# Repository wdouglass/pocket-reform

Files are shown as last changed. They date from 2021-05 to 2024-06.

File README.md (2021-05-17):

# MNT Pocket Reform (Research Project)

## License

Copyright 2021 MNT Research GmbH.

The following licenses are used in the project, unless specified differently in a particular subfolder:

- Schematics, PCBs: [CERN-OHL-S v2](https://www.ohwr.org/project/cernohl/wikis/uploads/002d0b7d5066e6b3829168730237bddb/cern_ohl_s_v2.txt)
- Other documentation, artwork, photos and drawings that are not trademarks (see below): [CC-BY-SA 4.0](https://creativecommons.org/licenses/by-sa/4.0/legalcode)
- Software, firmware: Various. [GPL 3.0](https://www.gnu.org/licenses/gpl-3.0.en.html) if not specified otherwise in the file/subdirectory.

The "MNT" and "MNT REFORM" logos are trademarks of MNT Research GmbH. You may not use these in derived works. The reason for this is that we cannot be responsible for regulatory issues with derived boards and we cannot support them. If someone sees an MNT brand on a product, it has to be clear that it comes from MNT Research and not from a third party.

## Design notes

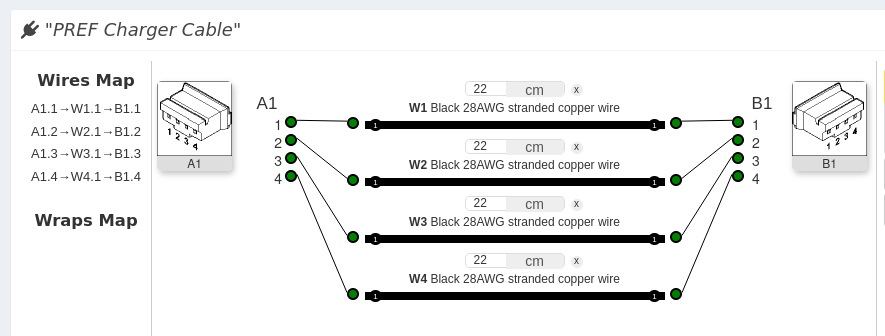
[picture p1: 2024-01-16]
pocket-reform-cables/pref-charger-cable.png

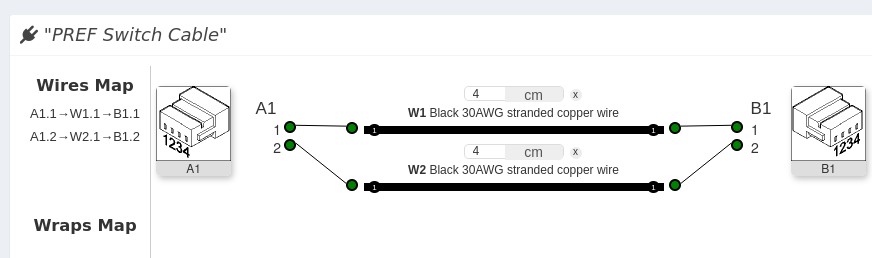
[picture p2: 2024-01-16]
pocket-reform-cables/pref-switch-cable.png

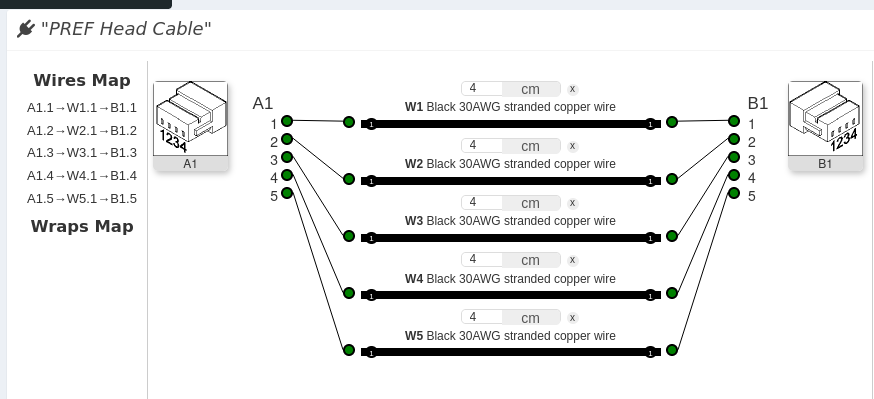
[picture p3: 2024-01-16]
pocket-reform-cables/pref-head-cable.png

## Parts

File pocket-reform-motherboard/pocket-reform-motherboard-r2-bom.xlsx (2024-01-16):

Reference | Value | Footprint | Manufacturer | Manufacturer_No | Qty
C1, C3, C13, C20, C25, C27-C33, C35, C38, C40, C42-C50, C53-C55, C57, C59-C64, C66, C68-C81, C84-C93, C95, C97, C99, C101, C104, C108, C109 | 0.1uF | Capacitor_SMD:C_0402_1005Metric | Samsung | CL05B104KO5NNNC | 66
C2, C4, C5, C39, C51, C56, C65, C98, C105, C107 | 10uF | Capacitor_SMD:C_0603_1608Metric | Samsung | CL10A106MO8NQNC | 10
C6, C17 | 22uF | Capacitor_SMD:C_0603_1608Metric | Samsung | CL10A226MP8NUNE | 2
C7, C8, C11, C12, C18, C19, C52, C58 | 10nF | Capacitor_SMD:C_0603_1608Metric | Samsung | CL10B103KB8NNNC | 8
C9, C10, C26, C34, C36, C41 | 1uF | Capacitor_SMD:C_0603_1608Metric | Samsung | CL10A105KB8NNNC | 6
C14, C83, C123, C124, C126 | 47uF | Capacitor_SMD:C_0603_1608Metric | Murata | GRM188R60J476ME15D | 5
C15, C16 | 330uF | Capacitor_SMD:CP_Elec_6.3x5.4 | Lelon | VZT331M0JTR-0606ACS | 2
C21, C23 | 18pF | Capacitor_SMD:C_0603_1608Metric | Yageo | CC0603JRNPO9BN180 | 2
C22, C24 | 27pF | Capacitor_SMD:C_0603_1608Metric | Yageo | CC0603JRNPO9BN270 | 2
C37 | 1nF | Capacitor_SMD:C_0603_1608Metric | Yageo | CC0603KRX7R9BB102 | 1
C67, C106 | 22uF | Capacitor_SMD:C_0805_2012Metric | Samsung | CL10A226MP8NUNE | 2
C82 | 470nF | Capacitor_SMD:C_0603_1608Metric | Samsung | CL10B474KA8NNNC | 1
C94, C100 | 10uF | Capacitor_SMD:C_0402_1005Metric | Samsung | CL05A106MP5NUNC | 2
C96 | DNP | Capacitor_SMD:C_0402_1005Metric | Samsung | CL05B104KO5NNNC | 1
C102, C103 | 47uF | Capacitor_SMD:C_1206_3216Metric | Murata | GRM31CR61A476ME15L | 2
D1 | LED_MODEM | LED_SMD:LED_0603_1608Metric | Everlight | 19-217/R6C-AL1M2VY/3T | 1
D2, D4-D6 | PMEG4050EP,115 | Diode_SMD:D_SOD-128 | Nexperia | PMEG4050EP,115 | 4
D3 | PMEG1020EA,115 | Diode_SMD:D_SOD-323 | Nexperia | PMEG1020EA,115 | 1
D8, D9 | LED_Small | LED_SMD:LED_0603_1608Metric | Everlight | 19-217/R6C-AL1M2VY/3T | 2
D10 | 19-337/R6GHBHC-A01/2T | footprints:LED_19-337_R6GHBHC-A01_2T | Everlight | 19-337/R6GHBHC-A01/2T | 1
D11 | SS54 | Diode_SMD:D_SMA | MDD | SS54 | 1
D12 | SD0603S040S0R2 | Diode_SMD:D_0603_1608Metric | AVX | SD0603S040S0R2 | 1
D23 | LED_NVME | LED_SMD:LED_0603_1608Metric | Everlight | 19-217/R6C-AL1M2VY/3T | 1
FB1, FB7, FB11 | 220@100MHz 1.4A | Inductor_SMD:L_0603_1608Metric | Murata | BLM18KG221SN1D | 3
FB2-FB4, FB6, FB8-FB10, FB12-FB16 | 100@100MHz 3A | Inductor_SMD:L_0603_1608Metric | Murata | BLM18PG121SN1D | 12
FB5 | DNP | Inductor_SMD:L_0603_1608Metric | Murata | BLM18PG121SN1D | 1
H5, H7 | NGFF-Mount1 | footprints:WA-SMSI-M2 | Wurth | SMTSO2020CTJ | 2
H8, H9 | MountingHole_Pad | footprints:WA-SMSI-M2 | Sinhoo | SMTSO2020CTJ | 2
J1 | CHARGER | Connector_JST:JST_PH_S9B-PH-SM4-TB_1x09-1MP_P2.00mm_Horizontal | HR(Joint Tech Elec) | A2001WR-S-09PD01 | 1
J2 | DM3AT-SF-PEJM5 | footprints:DM3AT-SF-PEJM5 | Hirose | DM3AT-SF-PEJM5 | 1
J3, J14 | USB_C_Receptacle | footprints:MOLEX_105450-0101 | Molex | 105450-0101 | 2
J4 | 9452812561 | footprints:09452812561 | HARTING | 9452812561 | 1
J5 | SYSCTL | Connector_JST:JST_SH_SM04B-SRSS-TB_1x04-1MP_P1.00mm_Horizontal | JST | SM04B-SRSS-TB(LF)(SN) | 1
J6 | USB_INT1 | Connector_JST:JST_SH_SM04B-SRSS-TB_1x04-1MP_P1.00mm_Horizontal | JST | SM04B-SRSS-TB(LF)(SN) | 1
J7 | HDMI_D_1.4 | Connector_HDMI:HDMI_Micro-D_Molex_46765-0x01 | Molex | 467650001 | 1
J8 | SIM_Card | footprints:MOLEX_78800-0001 | Molex | 788000001 | 1
J9 | USB_C_Receptacle_USB2.0 | Connector_USB:USB_C_Receptacle_HRO_TYPE-C-31-M-12 | Korean Hroparts | TYPE-C-31-M-12 | 1
J10 | 1-2199230-6 | footprints:TE_1-2199230-6 | TE | 1-2199230-6 | 1
J11 | Conn_01x33 | Connector_FFC-FPC:Hirose_FH12-33S-0.5SH_1x33-1MP_P0.50mm_Horizontal | Jushuo | AFC07-S33FCC-00 | 1
J12 | 2199230-5 | footprints:TE_2199230-5 | TE | 1-2199230-5 | 1
J13 | FH35C-31S-0.3HW(50) | footprints:TE_3-2328724-1 | TE | 3-2328724-1 | 1
J15 | CONN_SPK | Connector_Molex:Molex_PicoBlade_53261-0271_1x02-1MP_P1.25mm_Horizontal | Molex | 53261-7002 | 1
J16 | SAMTEC_TSM-106-02-X-SH-A | footprints:SAMTEC_TSM-106-02-X-SH-A | Samtec | TSM-106-01-T-SH | 1
J17 | POWSW | Connector_JST:JST_SH_SM02B-SRSS-TB_1x02-1MP_P1.00mm_Horizontal | JST | SM02B-SRSS-TB(LF)(SN) | 1
J18 | CONN_HEAD | Connector_JST:JST_SH_SM05B-SRSS-TB_1x05-1MP_P1.00mm_Horizontal | JST | SM05B-SRSS-TB(LF)(SN) | 1
J20 | QWIIC | Connector_JST:JST_SH_SM04B-SRSS-TB_1x04-1MP_P1.00mm_Horizontal | JST | SM04B-SRSS-TB(LF)(SN) | 1
J21 | USBSEL | Connector_PinHeader_2.00mm:PinHeader_2x03_P2.00mm_Vertical_SMD | Harwin | M22-5320305 | 1
L1 | 22uH | Inductor_SMD:L_Taiyo-Yuden_NR-30xx | YJYCOIN | YNR3015-150M | 1
L2 | 3.3uH | Inductor_SMD:L_1210_3225Metric | Murata | LQH32PN3R3NN0L | 1
L3, L4 | 15uH | Inductor_SMD:L_Vishay_IHLP-4040 | Vishay | IHLP4040DZER150M11 | 2
L5, L6 | 15uH | Inductor_SMD:L_Taiyo-Yuden_NR-30xx | Taiyo Yuden | NRH3012T150MN | 2
R1, R29, R34-R36, R58, R60, R61, R110 | 1k | Resistor_SMD:R_0402_1005Metric | Yageo | RC0402FR-071KL | 9
R2 | 1M | Resistor_SMD:R_0402_1005Metric | Yageo | AC0402FR-071ML | 1
R3 | 90.9K 1% | Resistor_SMD:R_0402_1005Metric | UNI-ROYAL | 0402WGF9092TCE | 1
R4, R5, R9, R11-R13, R19, R27, R33, R44-R46, R50, R53, R54, R65-R67, R81, R103-R109, R111 | 0 | Resistor_SMD:R_0402_1005Metric | Panasonic | ERJ2GE0R00X | 27
R6-R8, R69, R70, R87 | 100k | Resistor_SMD:R_0402_1005Metric | Yageo | RC0402FR-07100KL | 6
R10, R15, R17, R20, R22, R24, R26, R28, R30, R38, R52, R56, R68, R72, R75, R85, R96 | 10k | Resistor_SMD:R_0402_1005Metric | Yageo | RC0402FR-0710KL | 17
R14 | 8.25k | Resistor_SMD:R_0402_1005Metric | UNI-ROYAL | 0402WGF8251TCE | 1
R16 | 3.16k | Resistor_SMD:R_0402_1005Metric | Yageo | RC0402FR-073K16L | 1
R18 | 5.76k | Resistor_SMD:R_0402_1005Metric | UNI-ROYAL | 0402WGF5761TCE | 1
R21, R55, R62, R74, R78, R86, R88 | DNP | Resistor_SMD:R_0402_1005Metric | DNP | DNP | 7
R23 | 9.53K 1% | Resistor_SMD:R_0402_1005Metric | FH | RC-02W9531FT | 1
R25, R42, R43, R57, R59, R89, R93, R95, R101 | 4.7k | Resistor_SMD:R_0402_1005Metric | Yageo | RC0402FR-074K7L | 9
R37, R39-R41 | 75 1% | Resistor_SMD:R_0402_1005Metric | Panasonic | ERJ2RKF75R0X | 4
R47, R48 | 27.4 | Resistor_SMD:R_0402_1005Metric | UNI-ROYAL | 0402WGF274JTCE | 2
R64 | 2.2k | Resistor_SMD:R_0402_1005Metric | Yageo | RC0402FR-072K2L | 1
R73, R97-R100 | 47k | Resistor_SMD:R_0402_1005Metric | Yageo | AC0402FR-0747KL | 5
R76, R77, R79, R80, R82 | 33 | Resistor_SMD:R_0402_1005Metric | Yageo | RC0402FR-0733RL | 5
R83, R84 | 22k | Resistor_SMD:R_0402_1005Metric | Yageo | AC0402FR-0722KL | 2
R90 | 27k | Resistor_SMD:R_0402_1005Metric | Panasonic | ERJ2RKF2702X | 1
R198, R199 | 49.9 | Resistor_SMD:R_0402_1005Metric | Yageo | RC0402FR-0749R9L | 2
SW1 | SW_DIP_x01 | Button_Switch_SMD:SW_DIP_SPSTx01_Slide_Omron_A6S-110x_W8.9mm_P2.54mm | Dongguan Guangzhu | DSIC01LSGET | 1
SW2 | RESET | Button_Switch_SMD:SW_Push_1P1T_NO_CK_KMR2 | XKB | TS-1185EC-C-D-B | 1
TP5, TP6 | TestPoint | TestPoint:TestPoint_Pad_D1.0mm | DNP | DNP | 2
TR1 | TG111-MSC13LF | Transformer_SMD:Transformer_Ethernet_HALO_TG111-MSC13 | Heling | MT24-S1T1 | 1
U1 | reform2-som-connector | footprints:TE_1473149-4 | TE | 1473149-1 | 1
U2 | MAX1837EUT33+T | Package_TO_SOT_SMD:SOT-23-6 | Maxim | MAX1837EUT33+T | 1
U3 | LM2830XQMFE/NOPB | Package_TO_SOT_SMD:SOT-23-5 | Texas Instruments | LM2830XQMFE/NOPB | 1
U4 | TLV1117-18 | Package_TO_SOT_SMD:SOT-223 | ON | NCV1117ST18T3G | 1
U5, U6 | TPS5450DDAR | Package_SO:TI_SO-PowerPAD-8_ThermalVias | Texas Instruments | TPS5450DDAR | 2
U7 | 74LVC1G34 | Package_TO_SOT_SMD:SOT-353_SC-70-5 | Texas Instruments or UMW | SN74LVC1G34DCKR | 1
U8 | RP2040 | footprints:RP2040-QFN-56 | Raspberry Pi | RP2040 | 1
U9 | TPS7A0533PDBZ | Package_TO_SOT_SMD:SOT-23 | Texas Instruments | TPS7A0533PDBZ | 1
U10 | W25Q32JVSS | Package_SO:SOIC-8_5.23x5.23mm_P1.27mm | Winbond | W25Q32JVSS | 1
U11 | PCF8523T | Package_SO:SOIC-8_3.9x4.9mm_P1.27mm | NXP | PCF8523T/1,118 | 1
U12 | AP22815A | Package_TO_SOT_SMD:SOT-23-5 | Diodes, Inc. | AP22815AWT-7 | 1
U13, U24 | TXS0108EPW | Package_SO:TSSOP-20_4.4x6.5mm_P0.65mm | Texas Instruments | TXS0108EPW | 2
U14 | SN74AVC1T45 | Package_TO_SOT_SMD:SOT-23-6 | Texas Instruments | SN74AVC1T45DBVR | 1
U15, U16, U19-U22 | TPD4E02B04DQA | Package_SON:USON-10_2.5x1.0mm_P0.5mm | Texas Instruments | TPD4E02B04DQAR-TP | 6
U17 | TPD12S521 | footprints:TSSOP50P640X120-38N | Texas Instruments | TPD12S521 | 1
U18 | TLV320AIC3100 | Package_DFN_QFN:VQFN-32-1EP_5x5mm_P0.5mm_EP3.5x3.5mm | Texas Instruments | TLV320AIC3100 | 1
U23 | FUSB302BMPX | Package_DFN_QFN:WQFN-14-1EP_2.5x2.5mm_P0.5mm_EP1.45x1.45mm | ON Semi | FUSB302BMPX | 1
U25 | TUSB8041 | Package_DFN_QFN:QFN-64-1EP_9x9mm_P0.5mm_EP6x6mm_ThermalVias | Texas Instruments | TUSB8041 | 1
U26 | 74HC573 | Package_SO:TSSOP-20_4.4x6.5mm_P0.65mm | Nexperia | 74HC573PW,118 | 1
Y1 | 24MHz | Crystal:Crystal_SMD_Abracon_ABM8G-4Pin_3.2x2.5mm | Seiko Epson | X1E0000210264 | 1
Y2 | 12MHz 18pF | Crystal:Crystal_SMD_3225-4Pin_3.2x2.5mm | Seiko Epson | Q22FA23V0041800 | 1
Y3 | 32.768 kHz | Crystal:Crystal_SMD_3215-2Pin_3.2x1.5mm | Seiko Epson | Q13FC1350000200 | 1

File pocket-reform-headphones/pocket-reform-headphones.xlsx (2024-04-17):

Qty | Reference(s) | Value | Footprint | DNP | LCSC | Manufacturer | Manufacturer_No
3 | C2, C3, C4 | DNP | Capacitor_SMD:C_0603_1608Metric | DNP | DNP | DNP | DNP
1 | D1 | SP0503BAHT | Package_TO_SOT_SMD:SOT-143 |  | C3040626 | Littelfuse / TECH PUBLIC | SP0503BAHTG
1 | J1 | CONN_HEAD | Connector_JST:JST_SH_SM05B-SRSS-TB_1x05-1MP_P1.00mm_Horizontal |  | C136657 | JST | SM05B-SRSS-TB(LF)(SN)
1 | J2 | SJ-43516-SMT | footprints:SJ-43516-SMT |  |  | CUI | SJ-43516-SMT-TR
1 | J4 | CONN_PWRSW | Connector_JST:JST_SH_SM02B-SRSS-TB_1x02-1MP_P1.00mm_Horizontal |  | C160402 | JST | SM02B-SRSS-TB(LF)(SN)
1 | R1 | 47k | Resistor_SMD:R_0603_1608Metric |  |  | Generic | 47k 0603
3 | R2, R3, R4 | 0 | Resistor_SMD:R_0603_1608Metric |  |  | Generic | 0Ohms 0603
1 | SW1 | SW_DIP_x01 | Button_Switch_SMD:SW_SPDT_PCM12 |  | C319019 | XKB | SK-3296S-01-L3

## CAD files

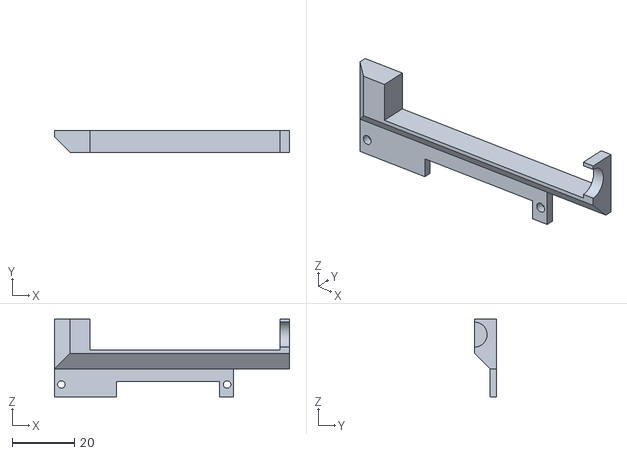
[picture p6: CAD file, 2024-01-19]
pref-battholder-openscad/pref-assembly-20240112-BattHolder1-reexport.stl
75.4 x 7.00 x 25.0

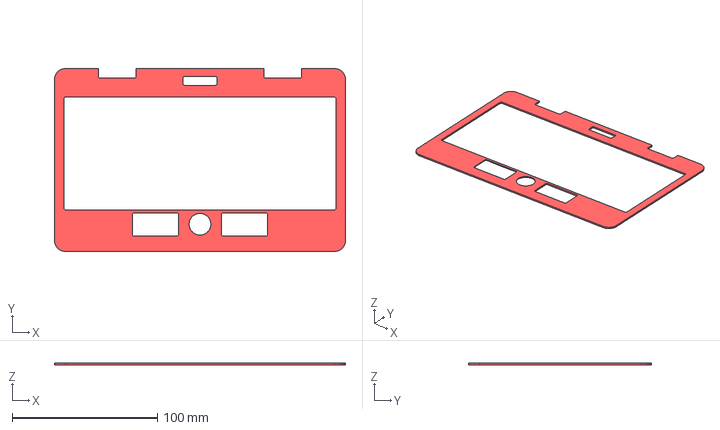
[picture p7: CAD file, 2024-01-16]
case-plate-pcbs/freecad/pref-keyboard-bezel-freecad-recreate.FCStd
200.2 x 125.8 x 1.20 mm

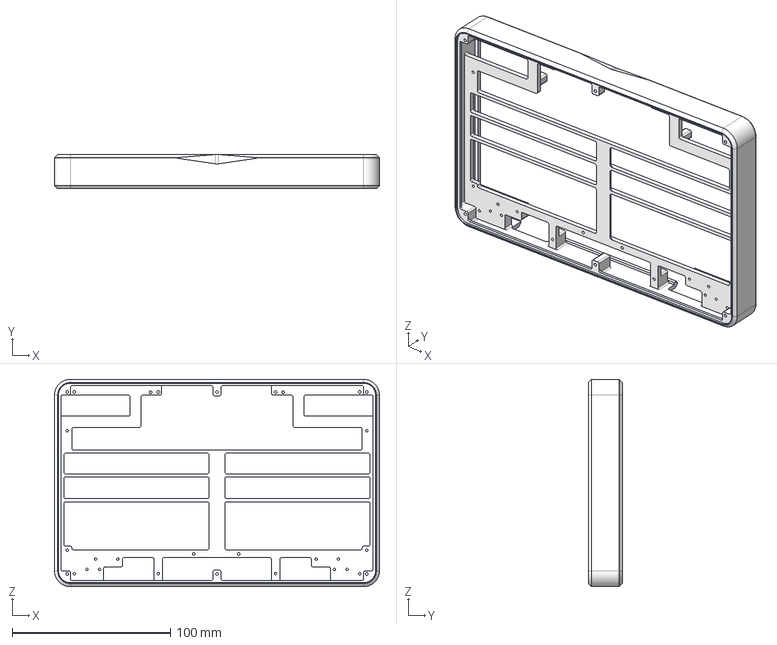
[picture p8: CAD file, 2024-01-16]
pocket-reform-case-20231121/PREF-bottom_enclosure_2023.09.06.step
205.4 x 21.7 x 131.0 mm

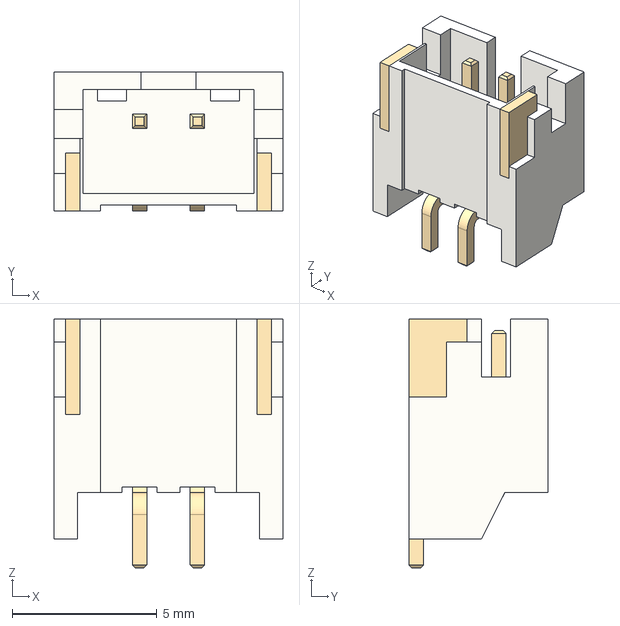
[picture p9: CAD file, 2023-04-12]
pocket-reform-charger/3d-models/S2B-PH-SM4-TB.stp
7.90 x 4.80 x 8.60 mm

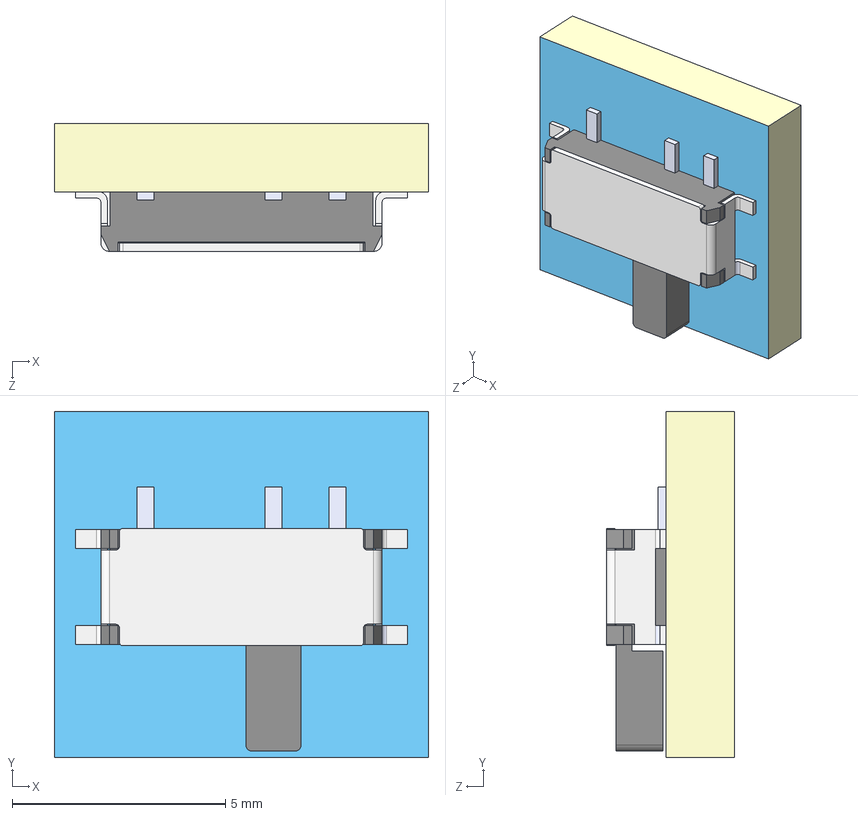
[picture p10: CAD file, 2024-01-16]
pocket-reform-headphones/3d-models/User Library-SK-3296S-01-L3-1.STEP
8.78 x 8.13 x 3.00 mm
SOLID.step
SOLID-0.step
SOLID-1.step
COMPOUND.step

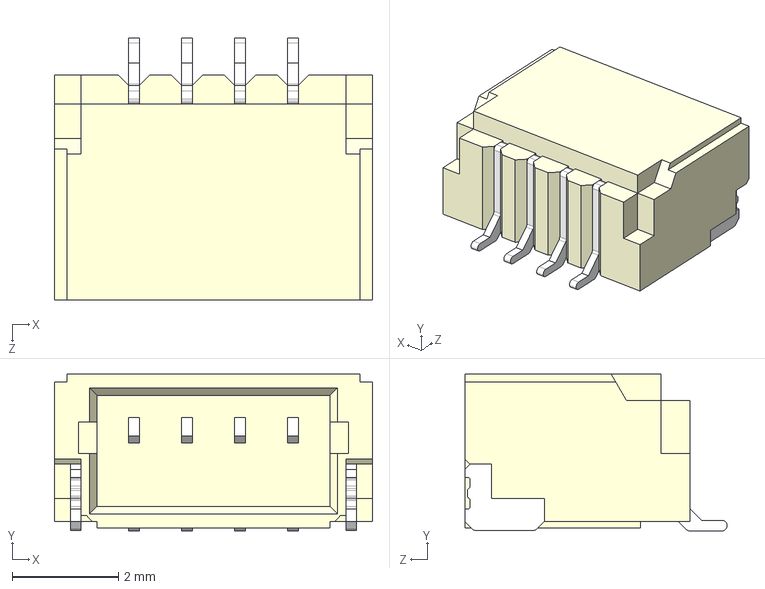
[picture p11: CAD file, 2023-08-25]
pocket-reform-keyboard-kailh-ortho/3d-models/SM04B-SRSS-TB(LF)(SN)--3DModel-STEP-56544.STEP
6.00 x 2.96 x 4.95 mm

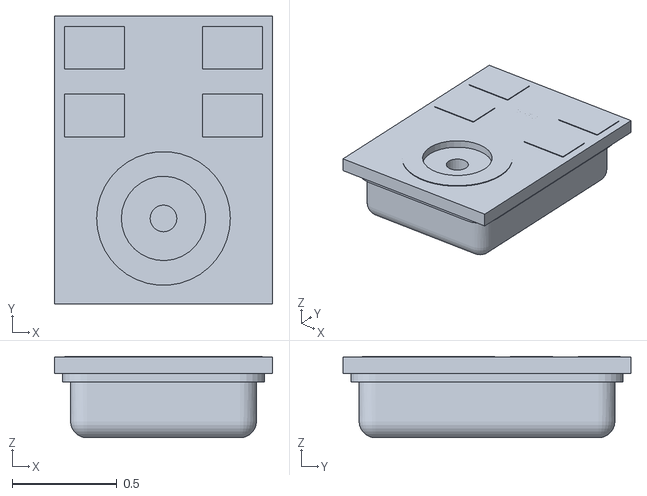
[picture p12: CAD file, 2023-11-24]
pocket-reform-motherboard/3d-models/MP23ABS1TR.obj
1.04 x 1.38 x 0.39

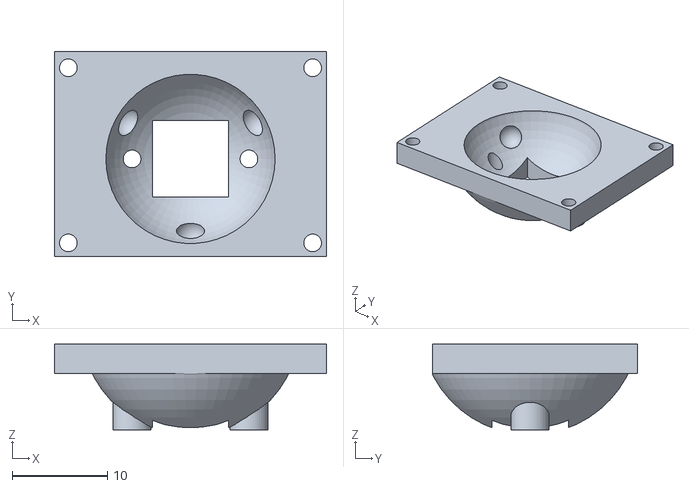
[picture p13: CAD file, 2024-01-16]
pocket-reform-trackball-cup/pocket-reform-trackball-cup-plate31.stl
28.5 x 21.5 x 9.00

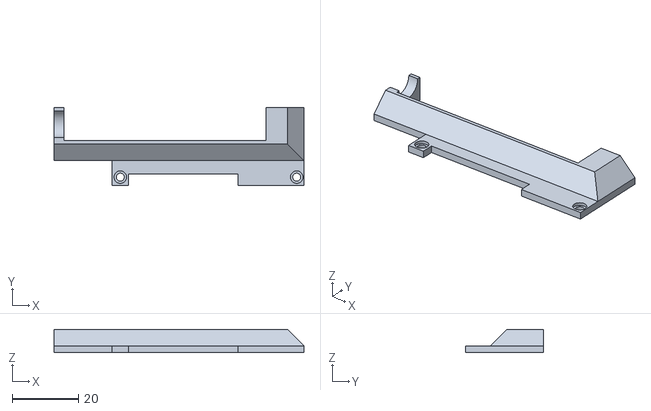
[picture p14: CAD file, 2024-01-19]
pref-battholder-openscad/pref-battholder-countersink-prod-a.stl
75.4 x 23.5 x 7.00

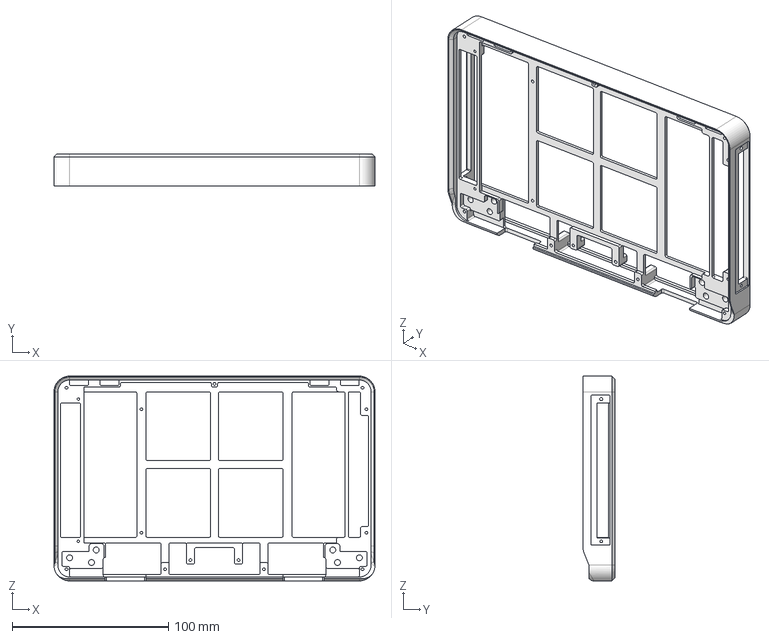
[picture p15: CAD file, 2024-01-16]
pocket-reform-case-20231121/PREF-top_enclosure_2023.11.21.step
205.4 x 20.8 x 131.0 mm

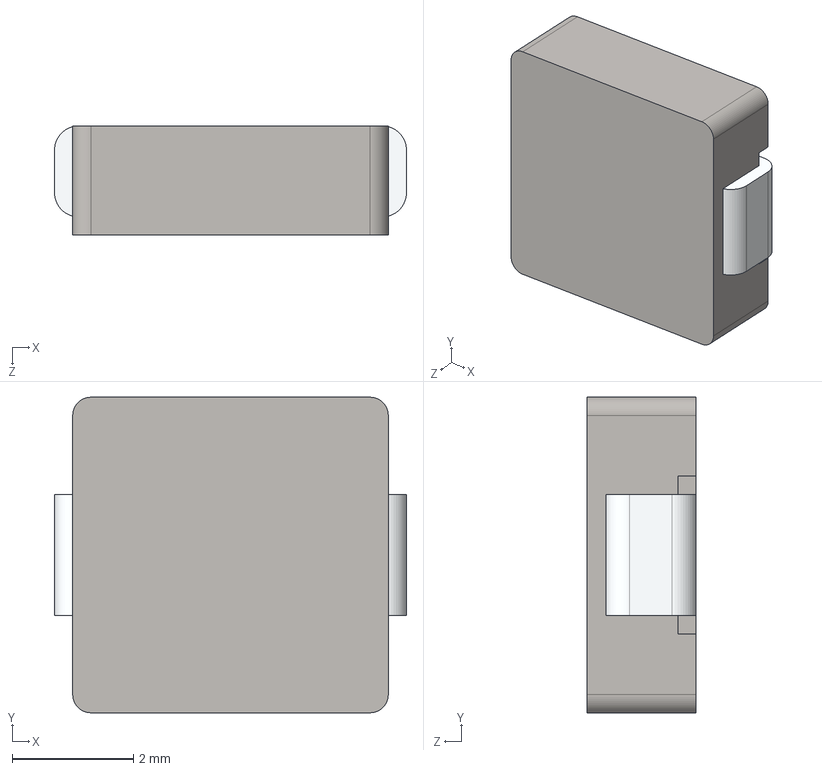
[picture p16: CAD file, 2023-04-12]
pocket-reform-charger/3d-models/User Library-MWSA0518S.STEP
5.80 x 5.20 x 1.80 mm
MWSA0518S-HOUSE
MWSA0518S-PIN

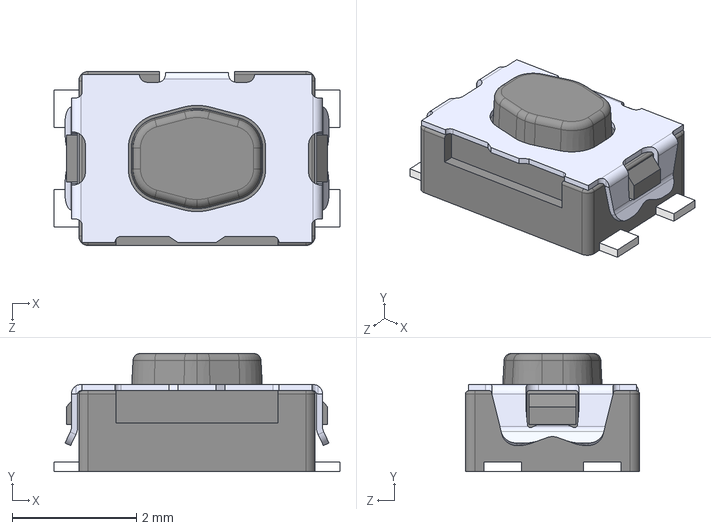
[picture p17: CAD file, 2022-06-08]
pocket-reform-keyboard-kailh-ortho/3d-models/KMR221GLFS.step
4.60 x 1.90 x 2.80 mm

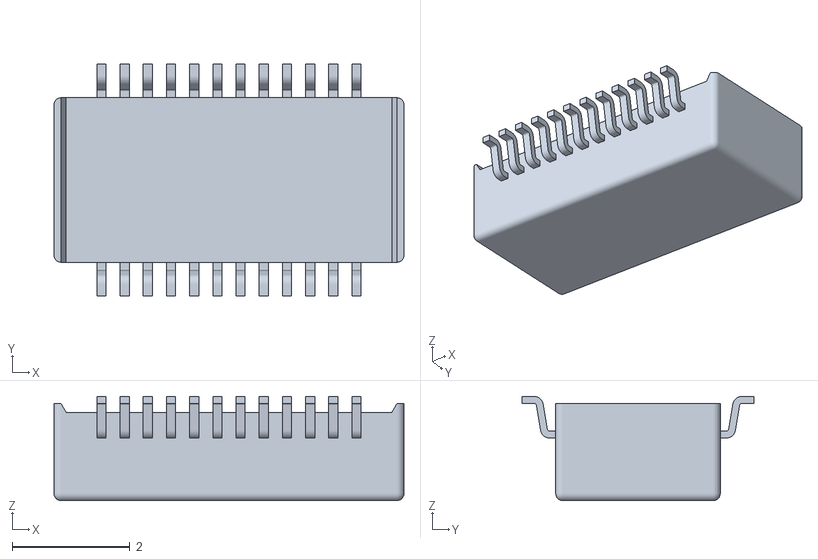
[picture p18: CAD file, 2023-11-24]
pocket-reform-motherboard/3d-models/JXD-G2406S.obj
5.94 x 3.94 x 1.77

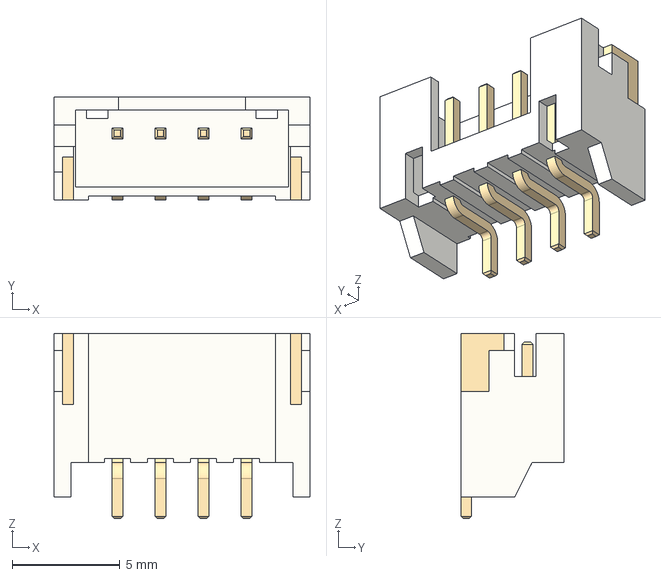
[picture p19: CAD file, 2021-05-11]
attic/pocket-reform-keyboard/3d-models/S4B-PH-SM4-TB.stp
11.9 x 4.80 x 8.60 mm

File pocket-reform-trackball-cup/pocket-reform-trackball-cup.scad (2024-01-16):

inner_d = 18.2;
outer_d = 23;
bearing_d = 2.5;
res = 50;
num_bearings = 3;
delta = 360 / num_bearings;
bearing_circle_r = 7.8;
bearing_circle_y = -3;
tube_h = 4.5;
offset = 30;
screw_d = 1.85;
screw_x = 12.8;
screw_y = 9.05;
screw_y2 = 9.3;
plate_thickness = 3.1; // was 2.6

difference() {
    union() {
        difference() {
            union() {
                translate([0,0,2]) sphere(d = outer_d, $fn = res);
                translate([-6.12, 0, -tube_h - tube_h/2]) cylinder(h = tube_h, d=4, $fn = res, center = true);
                translate([ 6.12, 0, -tube_h - tube_h/2]) cylinder(h = tube_h, d=4, $fn = res, center = true);
            }
            translate([-4,-4,-11]) cube([8,8,9]);
            translate([-12,-12,0]) cube([24,24,14]);

            union() {
                for (i = [0:2]) {
                    phi = offset + i * delta;
                    translate([
                        bearing_circle_r * cos(phi),
                        bearing_circle_r * sin(phi),
                        bearing_circle_y])
                    sphere(d = 0.5+bearing_d, $fn=res);
                }
                translate([0,0,2]) sphere(d = inner_d, $fn=res);
                
                // tube screw cuts
                translate([-6.12, 0, -tube_h - tube_h/2]) cylinder(h = tube_h+2, d=screw_d, $fn = res, center = true);
                translate([ 6.12, 0, -tube_h - tube_h/2]) cylinder(h = tube_h+2, d=screw_d, $fn = res, center = true);
            }
        }

        // bearings
        /*for (i = [0:2]) {
            phi = offset + i * delta;
            translate([
                bearing_circle_r * cos(phi),
                bearing_circle_r * sin(phi),
                bearing_circle_y])
            sphere(d = bearing_d, $fn=res);
        }*/
        
        // plate
        translate([0,0.5,0]) difference() {
            translate([0, 0, -plate_thickness/2]) cube([28.5, 21.5, plate_thickness], center = true);
            translate([0,-0.5,0]) translate([0, 0, plate_thickness]) sphere(d = outer_d-0.5, $fn = res);
            
            translate([-screw_x, screw_y, 0]) cylinder(h = 8, d=screw_d, $fn = res, center = true);
            translate([ screw_x, screw_y, 0]) cylinder(h = 8, d=screw_d, $fn = res, center = true);
            translate([-screw_x,-screw_y2, 0]) cylinder(h = 8, d=screw_d, $fn = res, center = true);
            translate([ screw_x,-screw_y2, 0]) cylinder(h = 8, d=screw_d, $fn = res, center = true);
        }

        // trackball itself
        //translate([0,0,1]) sphere(d = 15, $fn=res);
    }
    
    // cut away outer sphere overhang (due to assymetry)
    translate([0,-21.5/2 - 0.5,-plate_thickness/2]) cube([30,2,plate_thickness+1], center = true);
    
    // cut view
    //translate([0,0,-10]) cube(20, center=false);
};

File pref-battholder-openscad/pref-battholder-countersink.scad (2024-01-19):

mirror([0,0,0]) union() {
    difference() {
        rotate([-90,0,0]) import("pref-assembly-20240112-BattHolder1-reexport.stl");

        // countersinks
        translate([-35.5, -8.5, -2.3])
        cylinder(h = 1.2, r = 3.8/2, $fn = 20);
        translate([17.7, -8.5, -2.3])
        cylinder(h = 1.2, r = 3.8/2, $fn = 20);
        
        // cut off a bit
        translate([-39, -13, -4]) cube([60,2,4]);
    }

    // left and right extensions
    translate([19.7, -11, -3.5])
    cube([0.5,7.5,2]);
}

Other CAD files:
case-plate-pcbs/freecad/pref-keyboard-bezel-freecad-recreate-Cut.step
pref-battholder-openscad/pref-battholder-countersink-prod-b.stl
pocket-reform-charger/3d-models/21-0139I_T2444-4_MXM.step
pocket-reform-headphones/3d-models/SR42W001.stp
attic/pocket-reform-keyboard/3d-models/150080M153000.step
attic/pocket-reform-keyboard/3d-models/2005280040.stp
attic/pocket-reform-keyboard/3d-models/Cherry_-_ML1A-11NW.step
pocket-reform-charger/3d-models/S9B-PH-SM4-TB.stp
pocket-reform-headphones/3d-models/73412-0110.stp
pocket-reform-headphones/3d-models/CUI_SJ-43516-SMT-TR.step
pocket-reform-headphones/3d-models/SM05B-SRSS-TB(LF)(SN)--3DModel-STEP-418109.STEP
pocket-reform-motherboard/3d-models/105450-0101.step
pocket-reform-motherboard/3d-models/1747981-1.step
pocket-reform-motherboard/3d-models/19-337-R6GHBHC-A01-2T.STEP
pocket-reform-motherboard/3d-models/2199230-5.step
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

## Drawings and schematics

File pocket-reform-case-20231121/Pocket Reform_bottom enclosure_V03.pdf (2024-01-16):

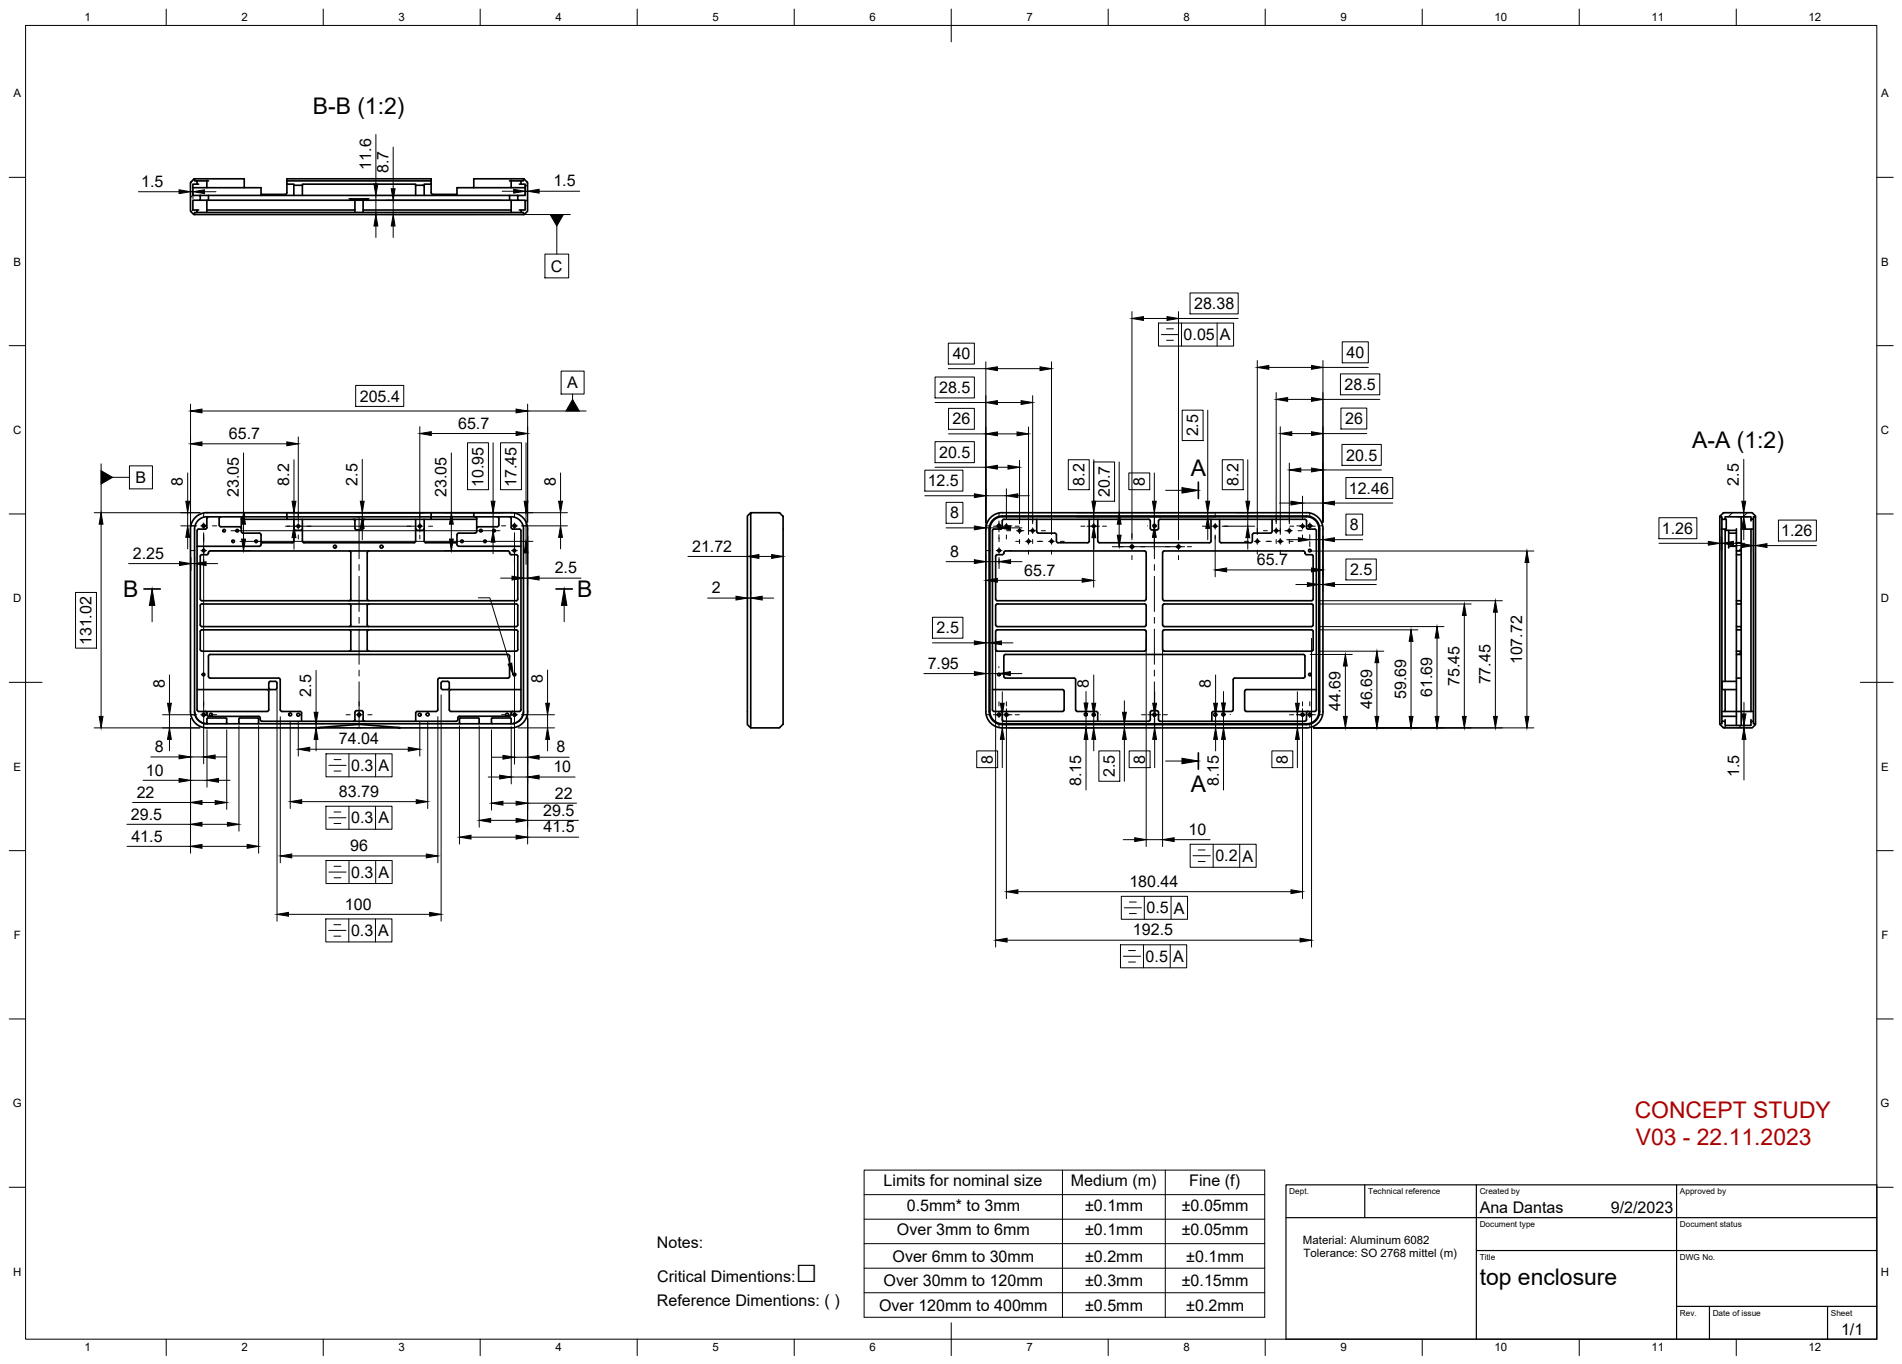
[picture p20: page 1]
Document type; Document status; Over 3mm to 6mm; Critical Dimentions:□; Reference Dimentions: ( ); CONCEPT STUDY V03 - 22.11.2023

Limits for nominal size | Medium (m) | Fine (f)
0.5mm* to 3mm | ±0.1mm | ±0.05mm

Dept. | Technical reference | Created by Ana Dantas 9/2/2023 | Approved by

Material: Aluminum 6082
Tolerance: SO 2768 mittel (m)

Over 6mm to 30mm | ±0.2mm | ±0.1mm
Over 30mm to 120mm | ±0.3mm | ±0.15mm
Over 120mm to 400mm | ±0.5mm | ±0.2mm

Title top enclosure | DWG No.

Rev. | Date of issue | Sheet 1/1

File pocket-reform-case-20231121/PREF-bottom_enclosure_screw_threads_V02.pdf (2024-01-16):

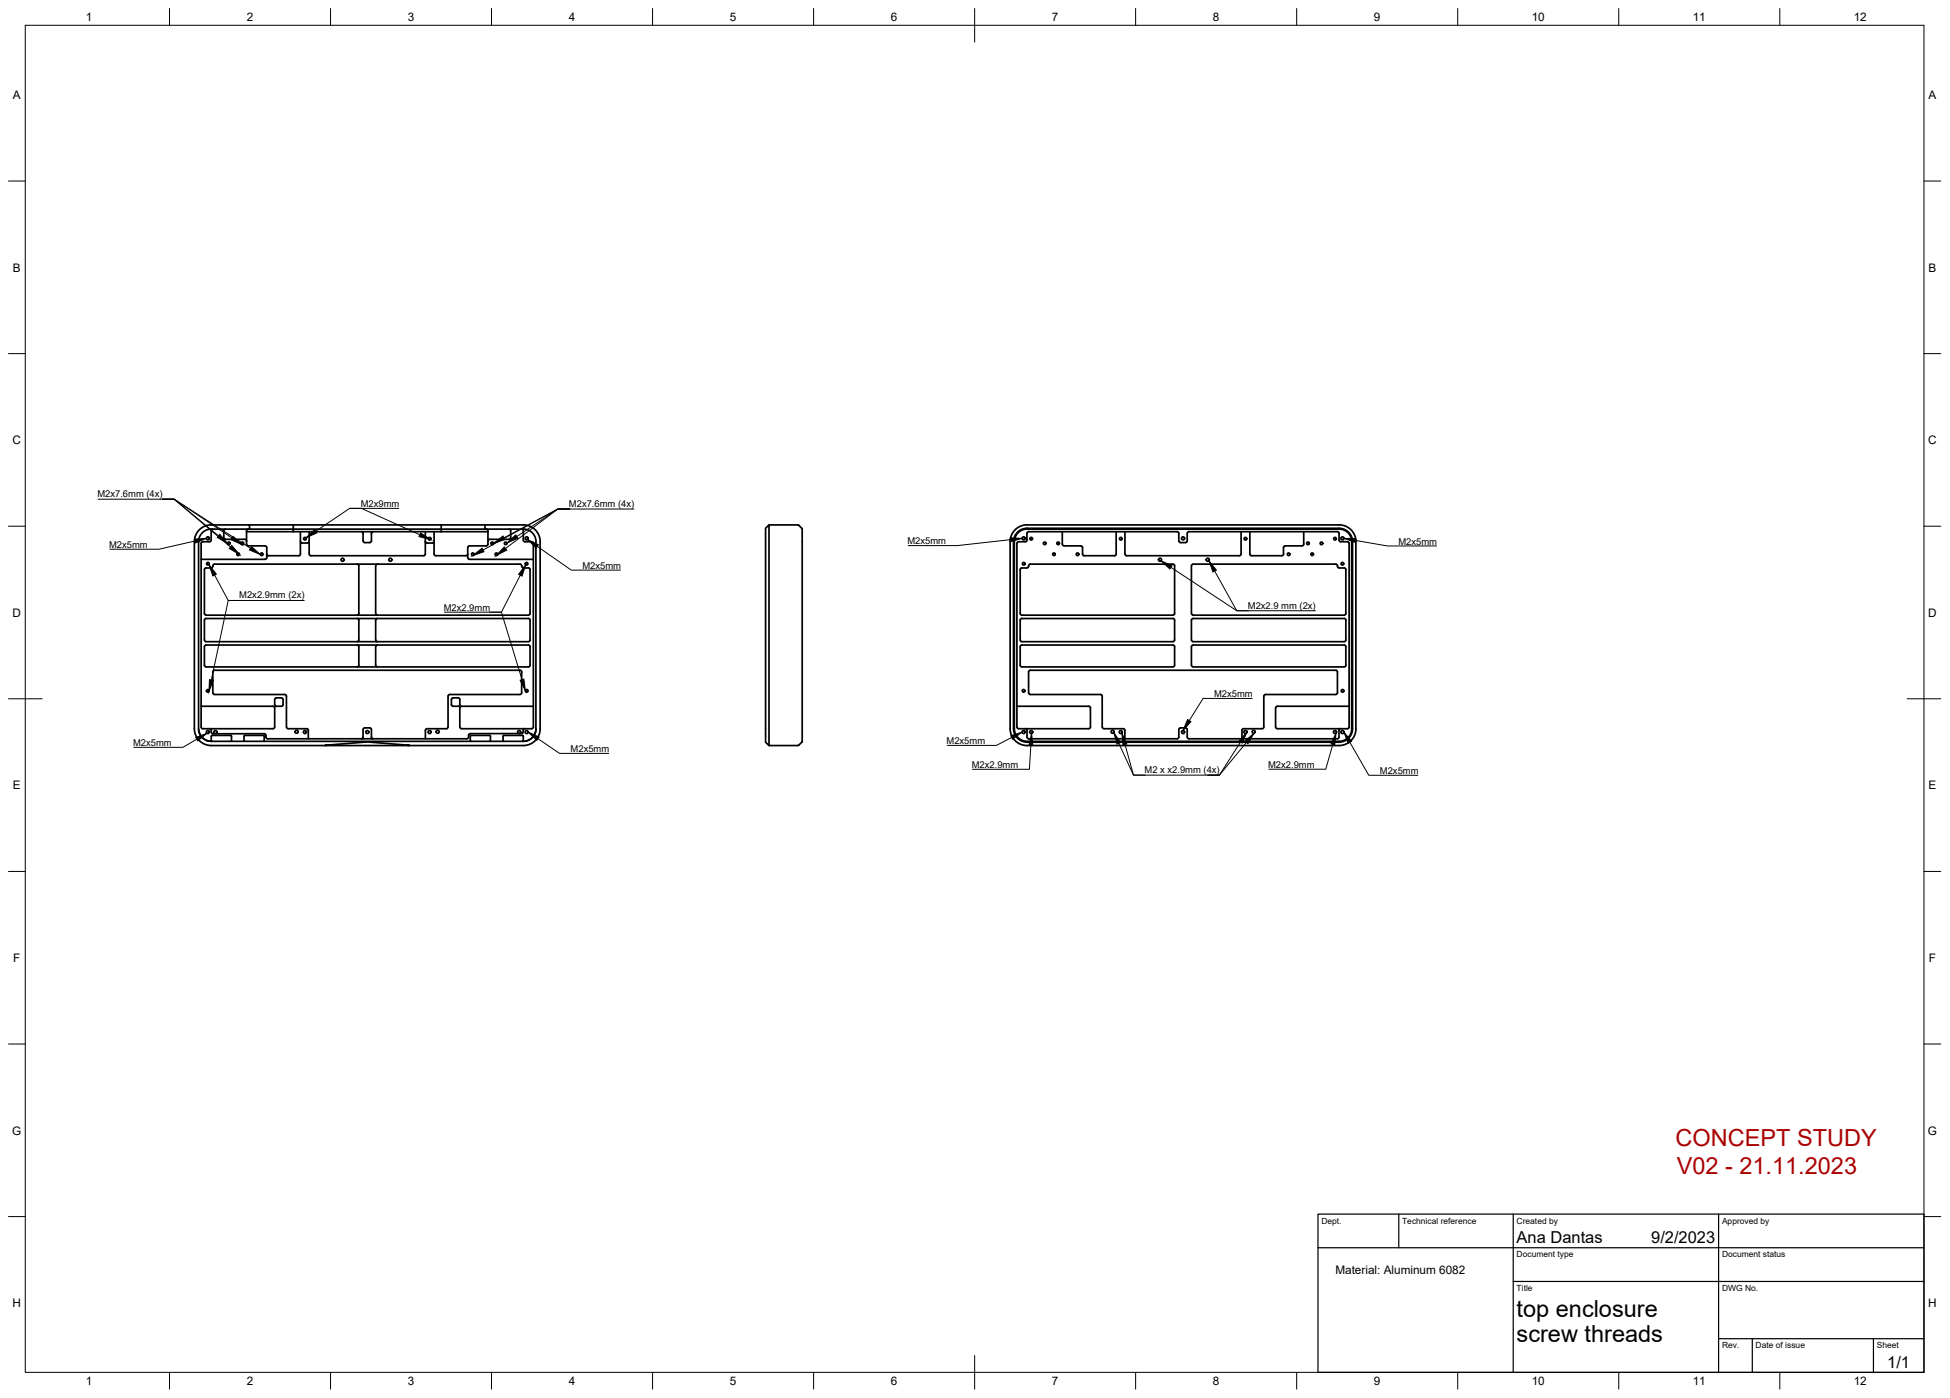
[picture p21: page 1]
CONCEPT STUDY V02 - 21.11.2023

Dept. | Technical reference | Created by Ana Dantas 9/2/2023 | Approved by

Material: Aluminum 6082 | | Document type | Document status

Title top enclosure screw threads | DWG No.

Rev. | Date of issue | Sheet 1/1

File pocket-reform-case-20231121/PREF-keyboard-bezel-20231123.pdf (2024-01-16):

6
5

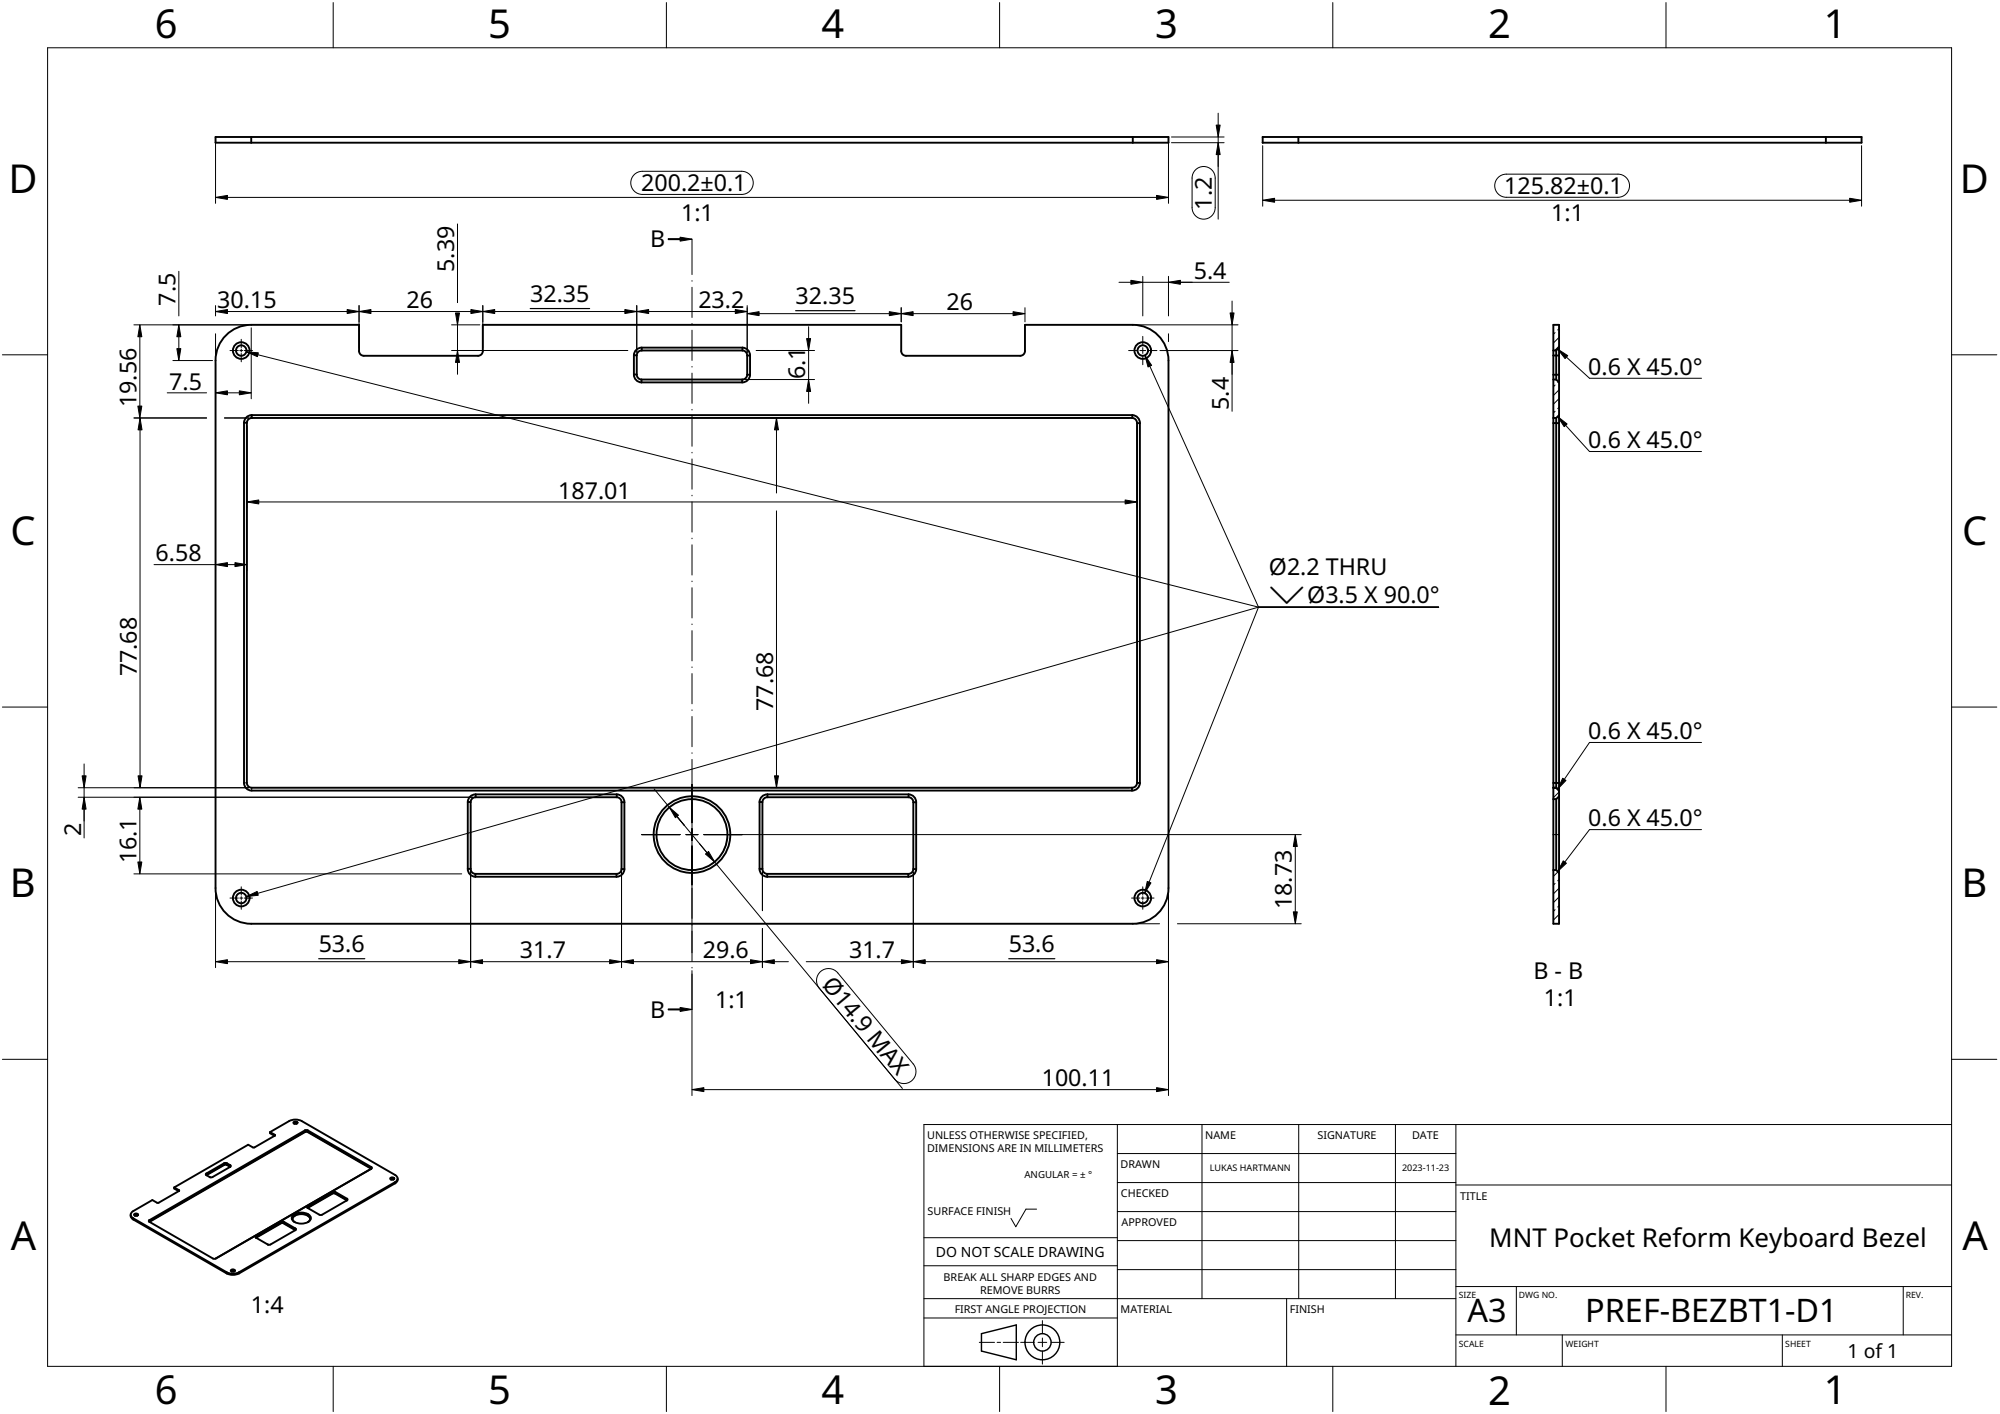
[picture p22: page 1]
MATERIAL; FINISH; Ø2.2 THRU Ø3.5 X 90.0°; Ø14.9 MAX

UNLESS OTHERWISE SPECIFIED, DIMENSIONS ARE IN MILLIMETERS ANGULAR = ± ° SURFACE FINISH | | NAME | SIGNATURE | DATE

DRAWN | LUKAS HARTMANN | | 2023-11-23

CHECKED | | | | TITLE MNT Pocket Reform Keyboard Bezel

APPROVED

DO NOT SCALE DRAWING

BREAK ALL SHARP EDGES AND

REMOVE BURRS
FIRST ANGLE PROJECTION

SIZE A3 | DWG NO. PREF-BEZBT1-D1 | REV.

SCALE | WEIGHT | SHEET

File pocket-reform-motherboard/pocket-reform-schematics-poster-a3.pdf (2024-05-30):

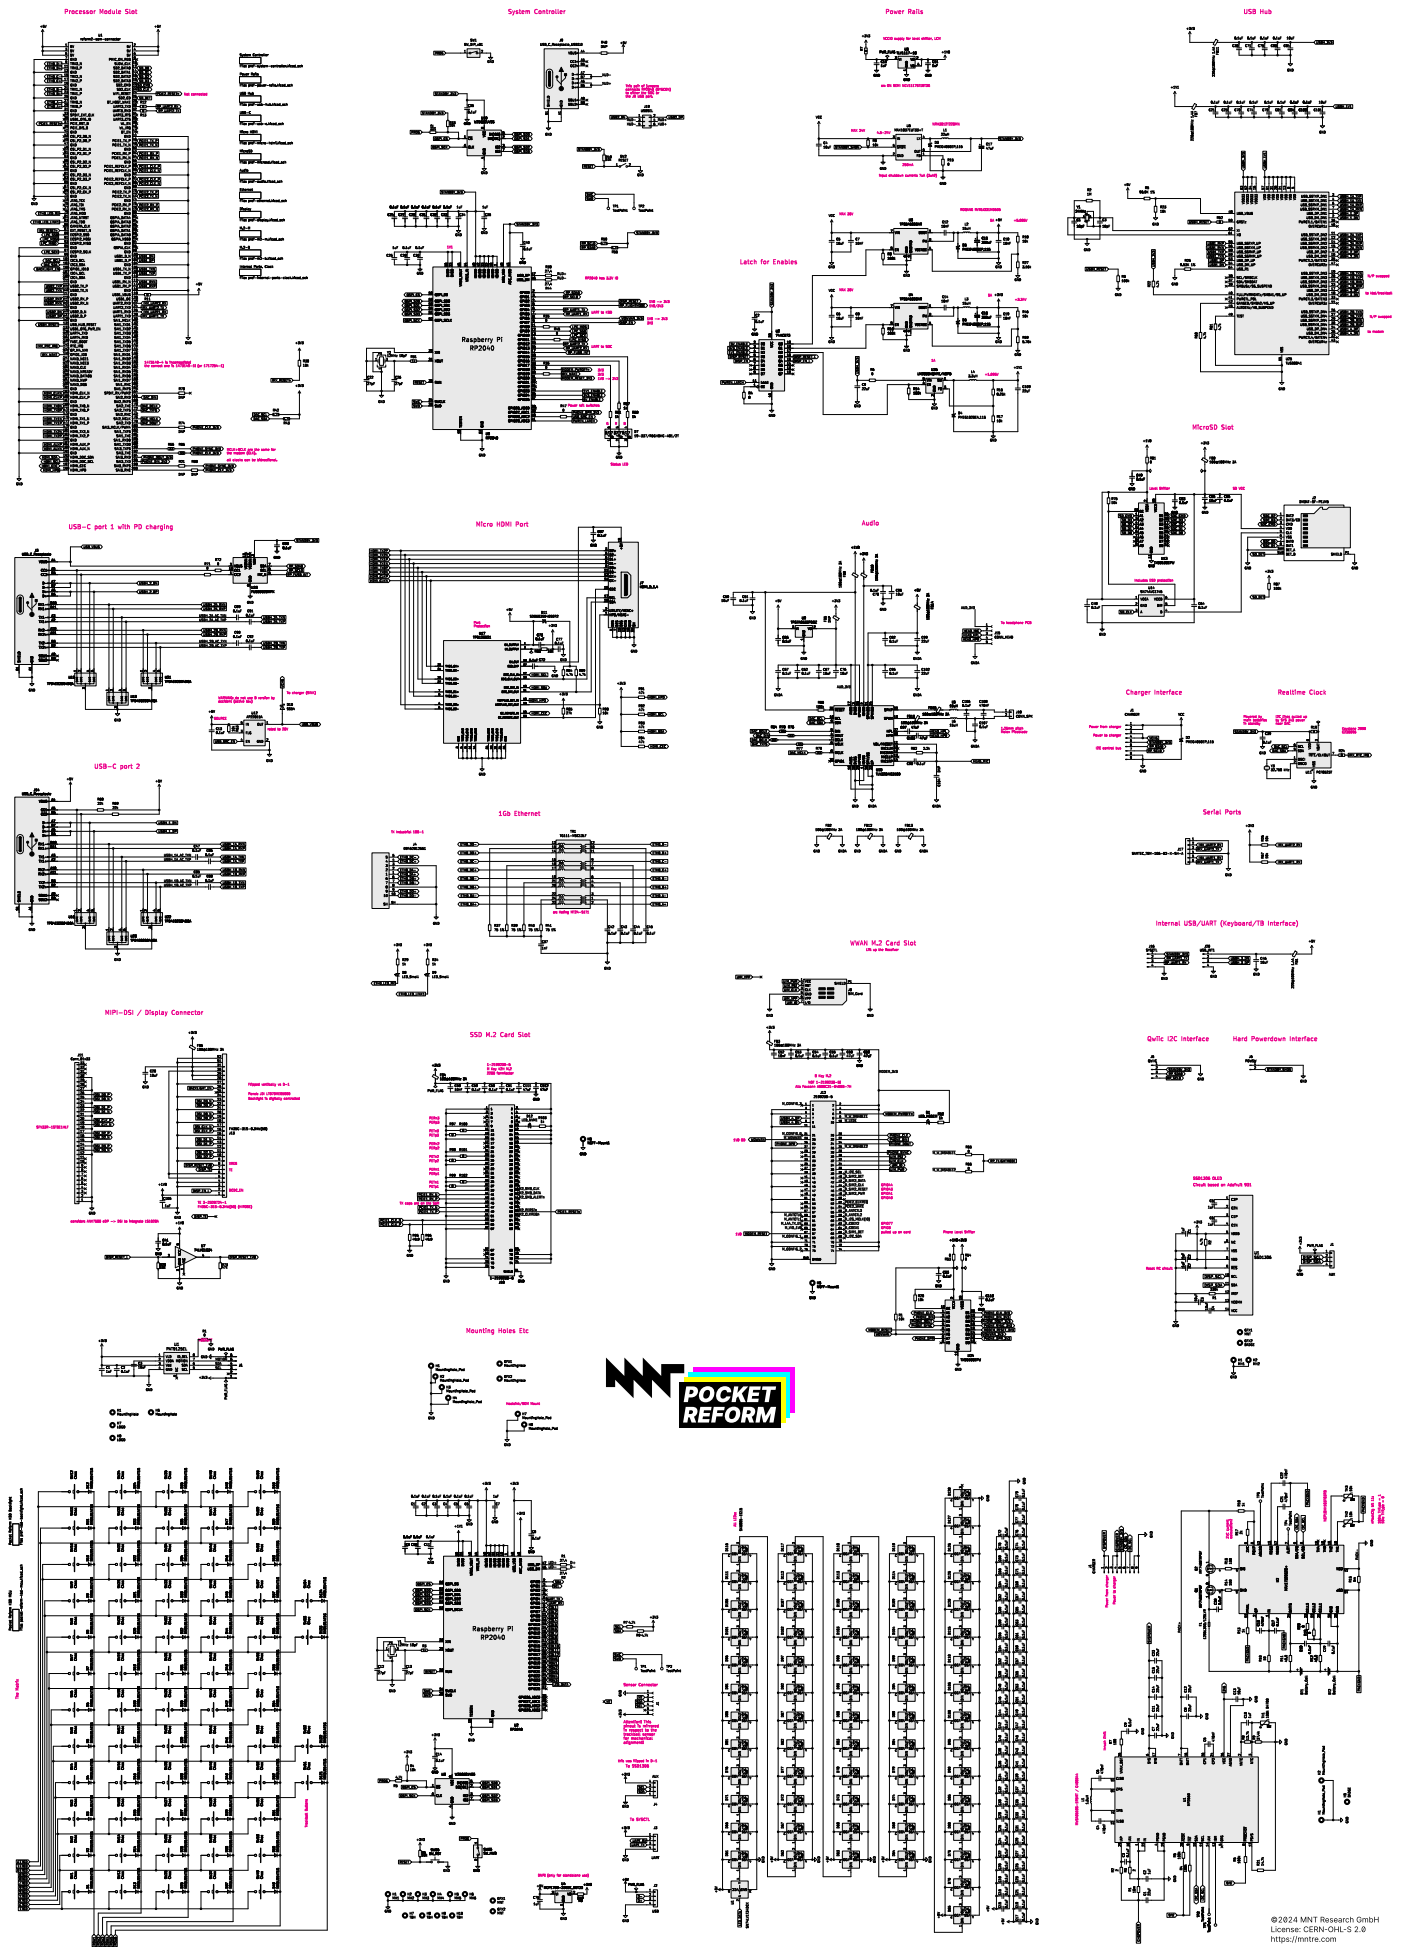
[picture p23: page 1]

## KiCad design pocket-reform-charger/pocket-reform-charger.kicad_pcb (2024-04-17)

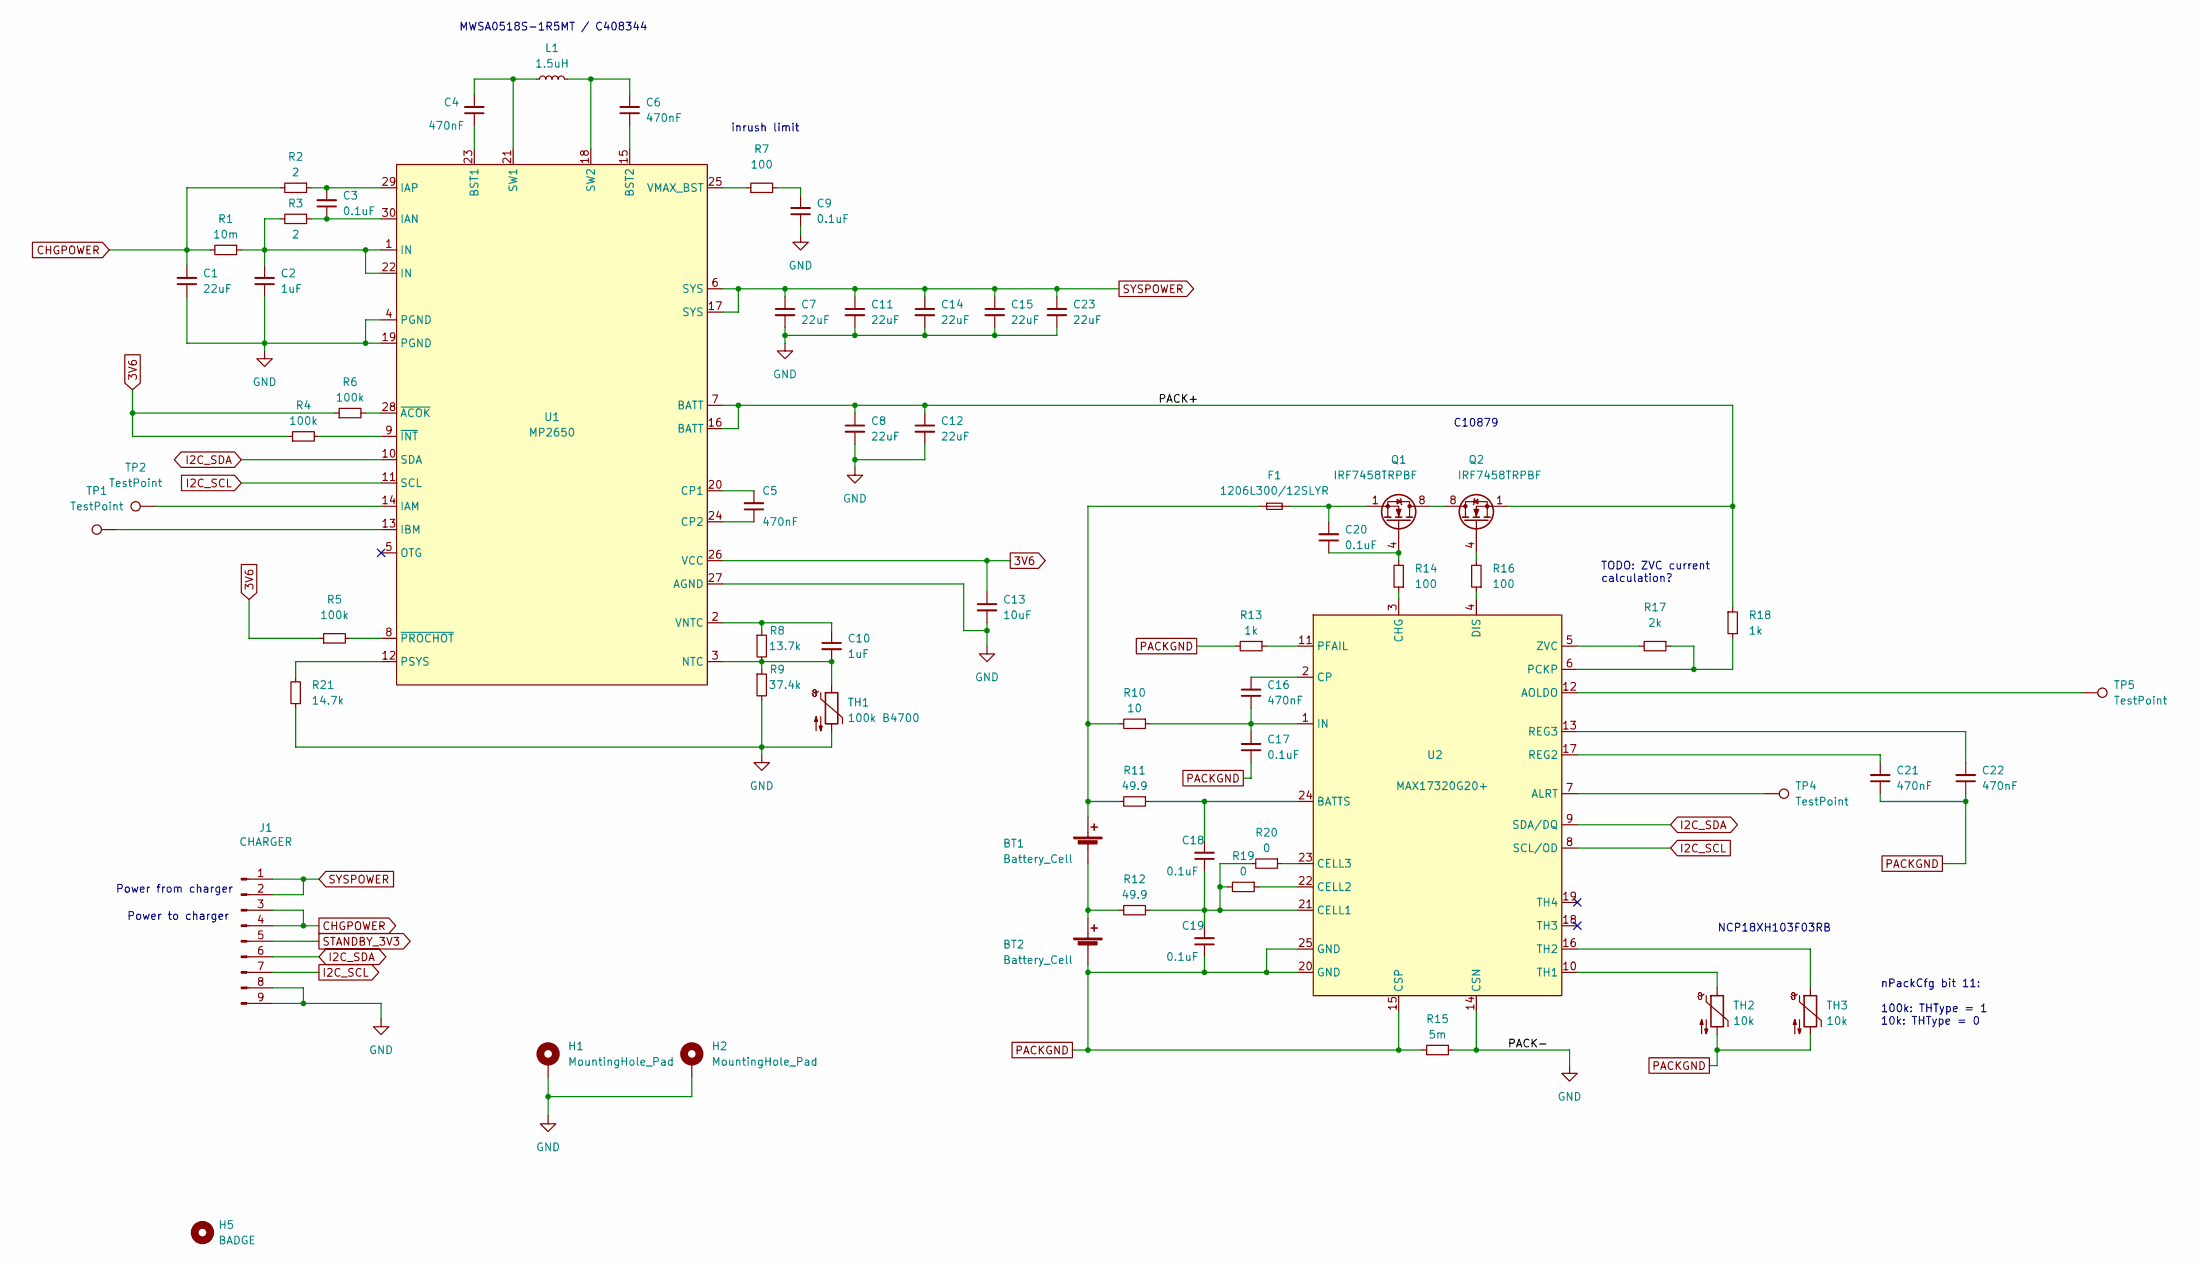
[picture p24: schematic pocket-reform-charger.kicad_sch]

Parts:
BT1, BT2: Battery_Cell; JST_PH_S2B-PH-SM4-TB_1x02-1MP_P2.00mm_Horizontal; LCSC C295747
C1, C7, C8, C11, C12, C14, C15, C23: 22uF; C_0805_2012Metric; LCSC C86816
C2, C10: 1uF; C_0603_1608Metric; LCSC C15849
C3, C9, C17, C18, C19, C20: 0.1uF; C_0603_1608Metric; LCSC C385964
C4, C5, C6, C16, C21, C22: 470nF; C_0603_1608Metric; LCSC C2905413
C13: 10uF; C_0603_1608Metric; LCSC C386081
F1: 1206L300/12SLYR; Fuse_1206_3216Metric; LCSC C1512043
H1, H2: MountingHole_Pad; MountingHole_2.2mm_M2_Pad
H5: BADGE; pocket-reform-charger-badge
J1: CHARGER; JST_PH_S9B-PH-SM4-TB_1x09-1MP_P2.00mm_Horizontal; LCSC C278795
L1: 1.5uH; L_Sunlord_MWSA0518_5.4x5.2mm; LCSC C408344
Q1, Q2: IRF7458TRPBF; SOIC-8_3.9x4.9mm_P1.27mm; LCSC C10879
R1: 10m; R_1206_3216Metric; LCSC C2961483
R2, R3: 2; R_0603_1608Metric; LCSC C403469
R4, R5, R6: 100k; R_0603_1608Metric; LCSC C189597
R7, R14, R16: 100; R_0603_1608Metric; LCSC C384296
R8: 13.7k; R_0603_1608Metric; LCSC C203293
R9: 37.4k; R_0603_1608Metric; LCSC C203565
R10: 10; R_0603_1608Metric; LCSC C193335
R11, R12: 49.9; R_0603_1608Metric; LCSC C403255
R13, R18: 1k; R_0603_1608Metric; LCSC C112433
R15: 5m; R_1206_3216Metric; LCSC C2937388
R17: 2k; R_0603_1608Metric; LCSC C163843
R19, R20: 0; R_0603_1608Metric
R21: 14.7k; R_0603_1608Metric; LCSC C100775
TH1: 100k B4700; R_0603_1608Metric; LCSC C153015
TH2, TH3: 10k; R_0603_1608Metric; LCSC C13564
TP1, TP2, TP4, TP5: TestPoint; TestPoint_Pad_1.0x1.0mm
U1: MP2650; MP2762A
U2: MAX17320G20+; QFN-24-1EP_4x4mm_P0.5mm_EP2.65x2.65mm_ThermalVias

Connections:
3V6: C13.1, R4.1, R5.1, R6.1, U1.26 (VCC)
/PACK+: C8.1, C12.1, Q2.1 (S), Q2.2 (S), Q2.3 (S), R18.1, U1.7 (BATT), U1.16 (BATT)
CHGPOWER: C1.2, J1.3, J1.4, R1.2, R2.2
GND: C1.1, C2.1, C7.2, C8.2, C9.1, C11.2, C12.2, C13.2, C14.2, C15.2, C23.2, H1.1, H2.1, J1.8, J1.9, R9.2, R15.1, R21.1, TH1.2, U1.4 (PGND), U1.19 (PGND), U1.27 (AGND), U2.14 (CSN)
I2C_SCL: J1.7, U1.11 (SCL), U2.8 (SCL/OD)
I2C_SDA: J1.6, U1.10 (SDA), U2.9 (SDA/DQ)
unnamed: BT1.1 (+), F1.1, R10.2, R11.2
unnamed: BT1.2 (-), BT2.1 (+), R12.2
unnamed: C2.2, R1.1, R3.2, U1.1 (IN), U1.22 (IN)
unnamed: C9.2, R7.2
unnamed: C20.2, F1.2, Q1.1 (S), Q1.2 (S), Q1.3 (S)
unnamed: Q1.5 (D), Q1.6 (D), Q1.7 (D), Q1.8 (D), Q2.5 (D), Q2.6 (D), Q2.7 (D), Q2.8 (D)
unnamed: C20.1, Q1.4 (G), R14.2
unnamed: Q2.4 (G), R16.2
unnamed: C4.1, U1.23 (BST1)
unnamed: C6.1, U1.15 (BST2)
unnamed: C5.2, U1.20 (CP1)
unnamed: C5.1, U1.24 (CP2)
unnamed: TP2.1, U1.14 (IAM)
unnamed: C3.1, R3.1, U1.30 (IAN)
unnamed: C3.2, R2.1, U1.29 (IAP)
unnamed: TP1.1, U1.13 (IBM)
unnamed: C10.2, R8.2, R9.1, TH1.1, U1.3 (NTC)
unnamed: R21.2, U1.12 (PSYS)
unnamed: C4.2, L1.1, U1.21 (SW1)
unnamed: C6.2, L1.2, U1.18 (SW2)
unnamed: R7.1, U1.25 (VMAX_BST)
unnamed: C10.1, R8.1, U1.2 (VNTC)
unnamed: R6.2, U1.28 (~ACOK)
unnamed: R4.2, U1.9 (~INT)
unnamed: R5.2, U1.8 (~PROCHOT)
unnamed: TP4.1, U2.7 (ALRT)
unnamed: TP5.1, U2.12 (AOLDO)
unnamed: C18.2, R11.1, U2.24 (BATTS)
unnamed: C18.1, C19.2, R12.1, R19.2, R20.2, U2.21 (CELL1)
unnamed: R19.1, U2.22 (CELL2)
unnamed: R20.1, U2.23 (CELL3)
unnamed: R14.1, U2.3 (CHG)
unnamed: C16.2, U2.2 (CP)
unnamed: R16.1, U2.4 (DIS)
unnamed: C16.1, C17.2, R10.1, U2.1 (IN)
unnamed: R17.1, R18.2, U2.6 (PCKP)
unnamed: R13.1, U2.11 (PFAIL)
unnamed: C21.2, U2.17 (REG2)
unnamed: C22.2, U2.13 (REG3)
unnamed: TH2.1, U2.10 (TH1)
unnamed: TH3.1, U2.16 (TH2)
unnamed: R17.2, U2.5 (ZVC)
PACKGND: BT2.2 (-), C17.1, C19.1, C21.1, C22.1, R13.2, R15.2, TH2.2, TH3.2, U2.15 (CSP), U2.20 (GND), U2.25 (GND)
STANDBY_3V3: J1.5
SYSPOWER: C7.1, C11.1, C14.1, C15.1, C23.1, J1.1, J1.2, U1.6 (SYS), U1.17 (SYS)

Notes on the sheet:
MWSA0518S-1R5MT / C408344
TODO: ZVC current calculation?
C10879
NCP18XH103F03RB
inrush limit
Power from charger
nPackCfg bit 11: 100k: THType = 1 10k: THType = 0
Power to charger

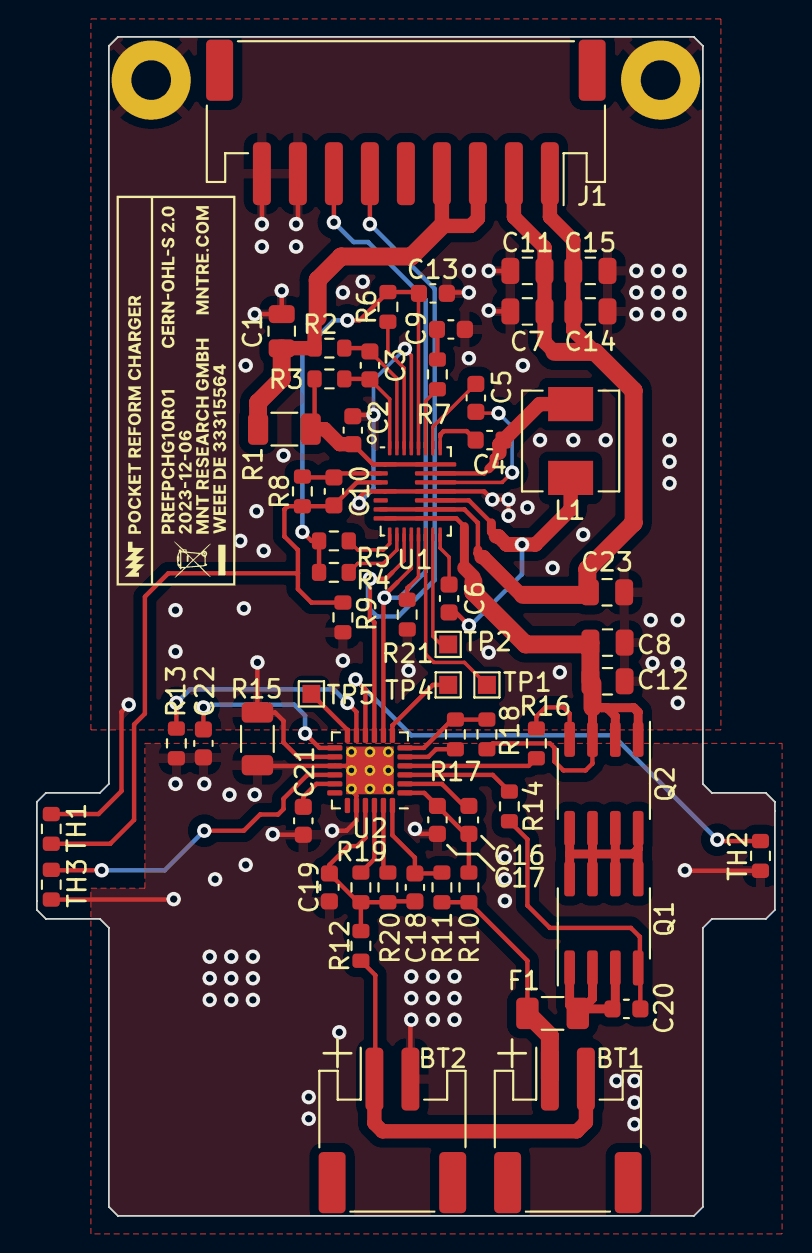
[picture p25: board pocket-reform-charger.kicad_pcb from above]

Board: 2 copper layers, 41.0 x 65.5 mm, 63 parts (0 on the bottom side), 50 nets.

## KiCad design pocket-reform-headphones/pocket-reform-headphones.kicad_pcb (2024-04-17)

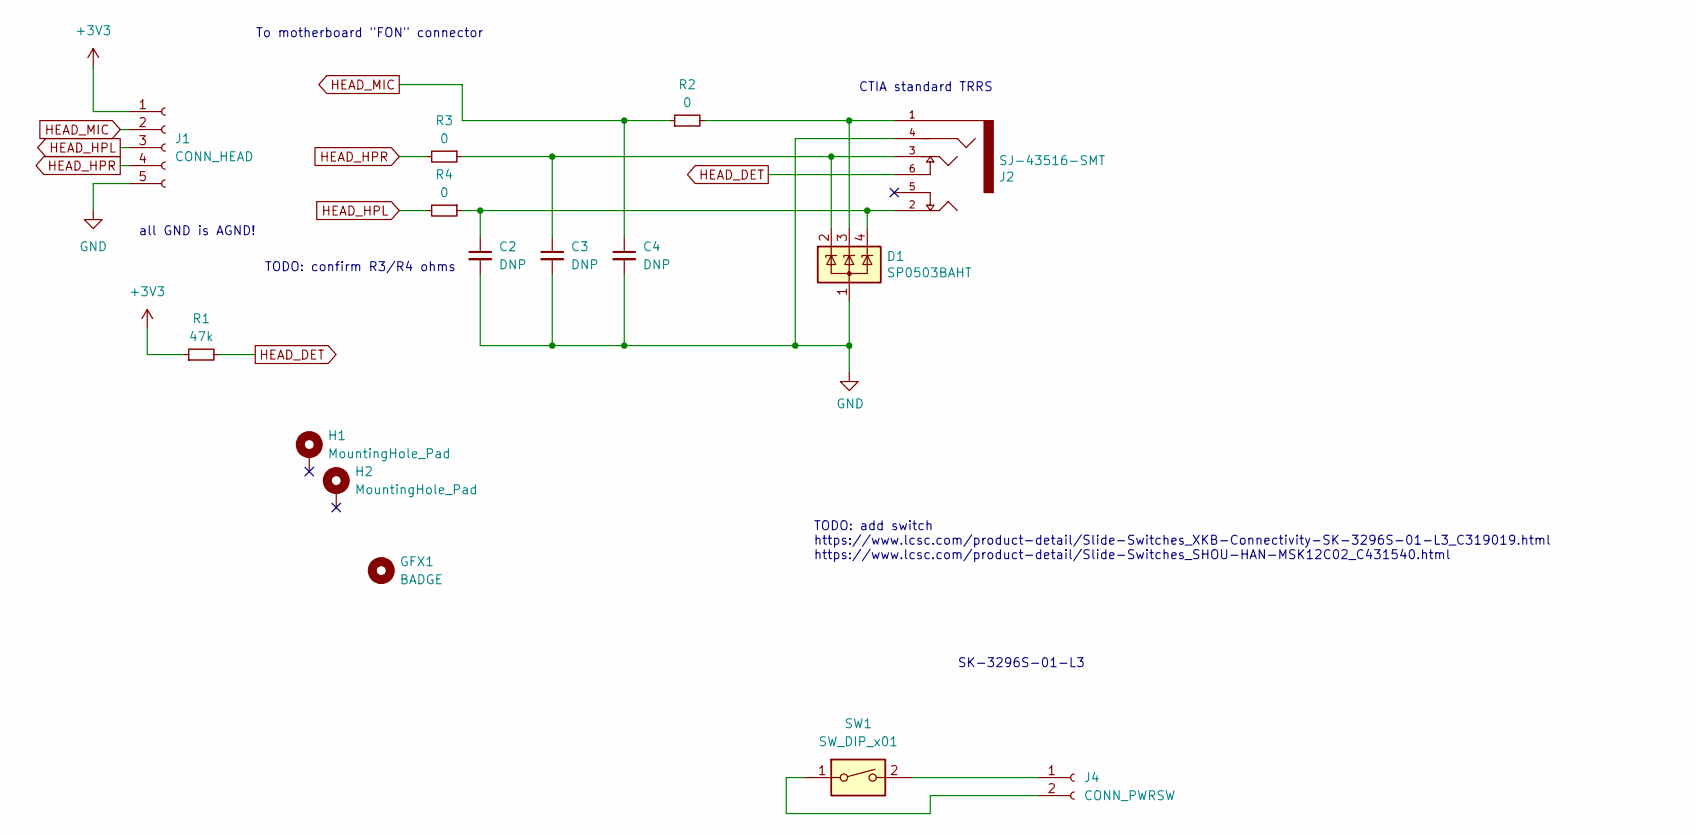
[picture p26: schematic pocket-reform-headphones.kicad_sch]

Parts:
C2, C3, C4: DNP; C_0603_1608Metric; LCSC DNP
D1: SP0503BAHT; SOT-143; LCSC C3040626
GFX1: BADGE; pref-headset-badge
H1, H2: MountingHole_Pad; MountingHole_2.2mm_M2_DIN965_Pad
J1: CONN_HEAD; JST_SH_SM05B-SRSS-TB_1x05-1MP_P1.00mm_Horizontal; LCSC C136657
J2: SJ-43516-SMT
J4: CONN_PWRSW; JST_SH_SM02B-SRSS-TB_1x02-1MP_P1.00mm_Horizontal; LCSC C160402
R1: 47k; R_0603_1608Metric
R2, R3, R4: 0; R_0603_1608Metric
SW1: SW_DIP_x01; SW_SPDT_PCM12; LCSC C319019

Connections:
+3V3: J1.1, R1.1
GND: C2.2, C3.2, C4.2, D1.1 (A), J1.5, J2.4 (RING2)
HEAD_DET: J2.6 (RING_SWITCH), R1.2
HEAD_HPL: J1.3, R4.2
HEAD_HPR: J1.4, R3.2
HEAD_MIC: C4.1, J1.2, R2.1
unnamed: C3.1, D1.2 (K), J2.3 (RING1), R3.1
unnamed: D1.3 (K), J2.1 (SLEEVE), R2.2
unnamed: C2.1, D1.4 (K), J2.2 (TIP), R4.1
unnamed: J4.1, SW1.2
unnamed: J4.2, SW1.1

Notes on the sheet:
SK-3296S-01-L3
To motherboard "FON" connector
TODO: add switch https://www.lcsc.com/product-detail/Slide-Switches_XKB-Connectivity-SK-3296S-01-L3_C319019.html https://www.lcsc.com/product-detail/Slide-Switches_SHOU-HAN-MSK12C02_C431540.html
all GND is AGND!
CTIA standard TRRS
TODO: confirm R3/R4 ohms

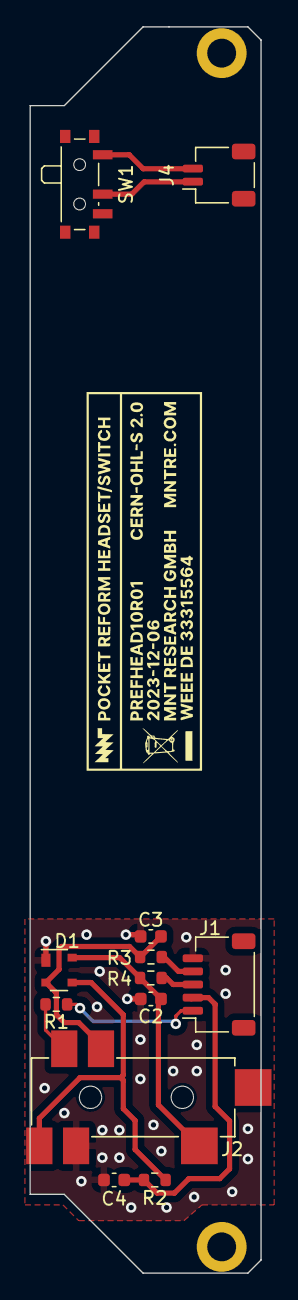
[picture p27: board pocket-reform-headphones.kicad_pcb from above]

Board: 2 copper layers, 17.6 x 95.0 mm, 15 parts (0 on the bottom side), 11 nets.

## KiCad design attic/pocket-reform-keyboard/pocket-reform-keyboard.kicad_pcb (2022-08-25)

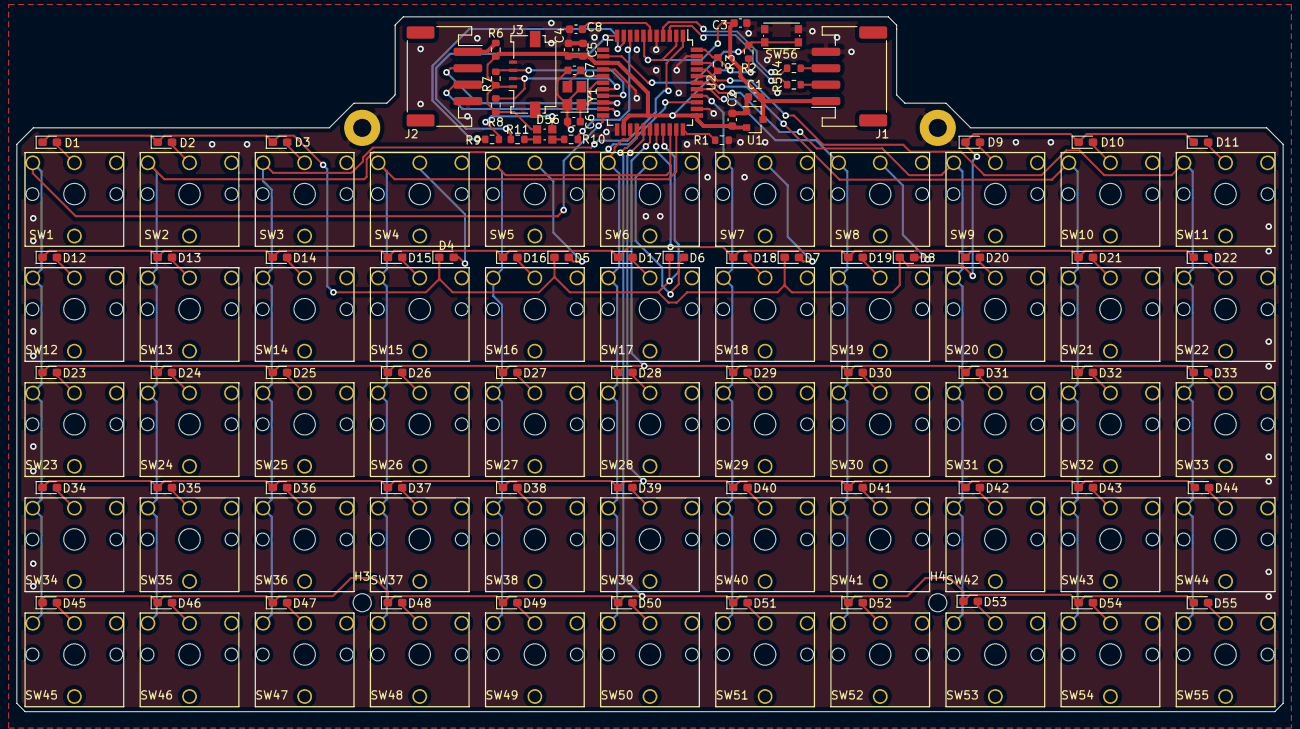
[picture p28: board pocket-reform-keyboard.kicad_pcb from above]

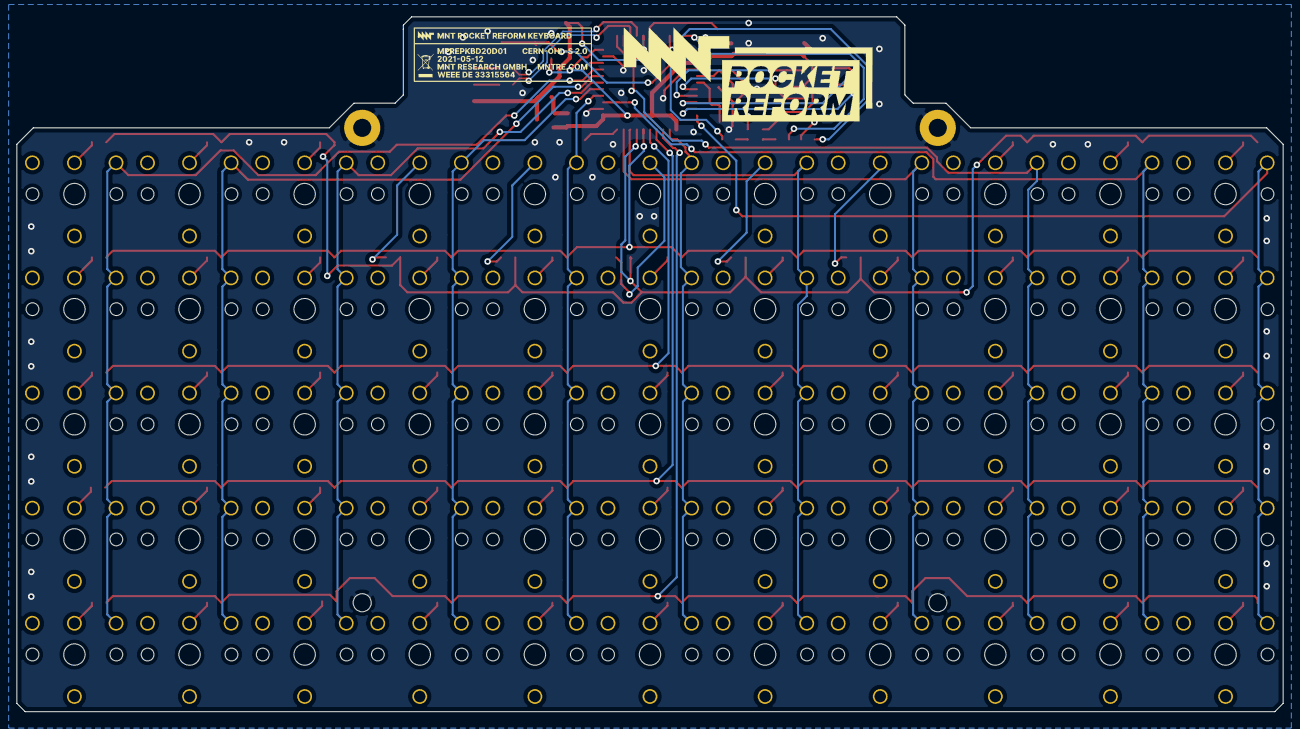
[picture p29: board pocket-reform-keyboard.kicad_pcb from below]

Board: 2 copper layers, 154.0 x 84.5 mm, 143 parts (2 on the bottom side), 95 nets.

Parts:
C1, C2, C4, C8: 1uF; C_0603_1608Metric
C3, C5: 0.1uF; C_0603_1608Metric
C6, C7: 18pF; C_0603_1608Metric
D1, D2, D3, D4, D5, D6, D7, D8, D9, D10, D11, D12, D13, D14, D15, D16, D17, D18, D19, D20, D21, D22, D23, D24, D25, D26, D27, D28, D29, D30, D31, D32, D33, D34, D35, D36, D37, D38, D39, D40, D41, D42, D43, D44, D45, D46, D47, D48, D49, D50, D51, D52, D53, D54, D55: MMDL914T1G; D_0603_1608Metric_Pad1.05x0.95mm_HandSolder
D56: LED_RGBA; LED_150080M153000
GFX1: MNT; pocket-reform
GFX2: MNT; mpre-badge-d1
H1: MH1; MountingHole_2.2mm_M2_Pad
H2: MH2; MountingHole_2.2mm_M2_Pad
H3: MH3; MountingHole_2.2mm_M2
H4: MH4; MountingHole_2.2mm_M2
J1: USB; JST_PH_S4B-PH-SM4-TB_1x04-1MP_P2.00mm_Horizontal
J2: UART; JST_PH_S4B-PH-SM4-TB_1x04-1MP_P2.00mm_Horizontal
J3: AUX; Molex_200528-0040_1x04-1MP_P1.00mm_Horizontal
R1, R3, R6: 0; R_0603_1608Metric
R2: 10k; R_0603_1608Metric
R4, R5: 22; R_0603_1608Metric
R7, R8: 4.7k; R_0603_1608Metric
R9: 220; R_0603_1608Metric
R10, R11: 47; R_0603_1608Metric
SW1, SW2, SW3, SW4, SW5, SW6, SW7, SW8, SW9, SW10, SW11, SW12, SW13, SW14, SW15, SW16, SW17, SW18, SW19, SW20, SW21, SW22, SW23, SW24, SW25, SW26, SW27, SW28, SW29, SW30, SW31, SW32, SW33, SW34, SW35, SW36, SW37, SW38, SW39, SW40, SW41, SW42, SW43, SW44, SW45, SW46, SW47, SW48, SW49, SW50, SW51, SW52, SW53, SW54, SW55: Choc; cherry-ml
SW56: RESET; SW_Push_1P1T_NO_CK_KMR2
U1: MCP1700-3302E_SOT23; SOT-23
U2: ATMEGA32U4-AU; TQFP-44_10x10mm_P0.8mm
Y1: 16MHz; Crystal_SMD_3225-4Pin_3.2x2.5mm

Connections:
+3V3: C2.1, C4.1, C5.1, D56.4, J3.1, R2.1, R3.2, R6.2, R7.1, R8.1, U1.2, U2.14, U2.24, U2.34, U2.44
+5V: C1.1, C3.1, J1.1, U1.3, U2.2, U2.7
/Pocket Reform Keyboard MCU/UD+: R4.1, U2.4
/Pocket Reform Keyboard MCU/UD-: R5.1, U2.3
COL1: SW1.1, SW12.1, SW23.1, SW34.1, SW45.1, U2.22
COL2: SW2.1, SW13.1, SW24.1, SW35.1, SW46.1, U2.36
COL3: SW3.1, SW14.1, SW25.1, SW36.1, SW47.1, U2.1
COL4: SW4.1, SW15.1, SW26.1, SW37.1, SW48.1, U2.32
COL5: SW5.1, SW16.1, SW27.1, SW38.1, SW49.1, U2.31
COL6: SW6.1, SW17.1, SW28.1, SW39.1, SW50.1, U2.25
COL7: SW7.1, SW18.1, SW29.1, SW40.1, SW51.1, U2.37
COL8: SW8.1, SW19.1, SW30.1, SW41.1, SW52.1, U2.38
COL9: SW9.1, SW20.1, SW31.1, SW42.1, SW53.1, U2.39
COL10: SW10.1, SW21.1, SW32.1, SW43.1, SW54.1, U2.40
COL11: SW11.1, SW22.1, SW33.1, SW44.1, SW55.1, U2.41
D+: J1.3, R4.2
D-: J1.2, R5.2
DISP_SCL: J3.2, R8.2, U2.18
DISP_SDA: J3.3, R7.2, U2.19
GND: C1.2, C2.2, C3.2, C4.2, C5.2, C6.2, C7.2, C8.2, H1.1, H2.1, H3.1, H4.1, J1.4, J2.4, J3.4, R1.1, SW56.2, U1.1, U2.5, U2.15, U2.23, U2.35, U2.43, Y1.2, Y1.4
unnamed: C6.1, U2.17, Y1.1
unnamed: C7.1, U2.16, Y1.3
unnamed: C8.1, U2.6
unnamed: D1.2, SW1.2
unnamed: D2.2, SW2.2
unnamed: D3.2, SW3.2
unnamed: D4.2, SW4.2
unnamed: D5.2, SW5.2
unnamed: D6.2, SW6.2
unnamed: D7.2, SW7.2
unnamed: D8.2, SW8.2
unnamed: D9.2, SW9.2
unnamed: D10.2, SW10.2
unnamed: D11.2, SW11.2
unnamed: D12.2, SW12.2
unnamed: D13.2, SW13.2
unnamed: D14.2, SW14.2
unnamed: D15.2, SW15.2
unnamed: D16.2, SW16.2
unnamed: D17.2, SW17.2
unnamed: D18.2, SW18.2
unnamed: D19.2, SW19.2
unnamed: D20.2, SW20.2
unnamed: D21.2, SW21.2
unnamed: D22.2, SW22.2
unnamed: D23.2, SW23.2
unnamed: D24.2, SW24.2
unnamed: D25.2, SW25.2
unnamed: D26.2, SW26.2
unnamed: D27.2, SW27.2
unnamed: D28.2, SW28.2
unnamed: D29.2, SW29.2
unnamed: D30.2, SW30.2
unnamed: D31.2, SW31.2
unnamed: D32.2, SW32.2
unnamed: D33.2, SW33.2
unnamed: D34.2, SW34.2
unnamed: D35.2, SW35.2
unnamed: D36.2, SW36.2
unnamed: D37.2, SW37.2
unnamed: D38.2, SW38.2
unnamed: D39.2, SW39.2
unnamed: D40.2, SW40.2
unnamed: D41.2, SW41.2
unnamed: D42.2, SW42.2
unnamed: D43.2, SW43.2
unnamed: D44.2, SW44.2
unnamed: D45.2, SW45.2
unnamed: D46.2, SW46.2
unnamed: D47.2, SW47.2
unnamed: D48.2, SW48.2
unnamed: D49.2, SW49.2
unnamed: D50.2, SW50.2
unnamed: D51.2, SW51.2
unnamed: D52.2, SW52.2
unnamed: D53.2, SW53.2
unnamed: D54.2, SW54.2
unnamed: D55.2, SW55.2
unnamed: D56.1, R9.1
unnamed: D56.2, R10.1
unnamed: D56.3, R11.1
unnamed: J2.1, R6.1
unnamed: R3.1, U2.42
unnamed: R9.2, U2.10
unnamed: R10.2, U2.9
unnamed: R11.2, U2.11
PROG: R1.2, U2.33
RESET: R2.2, SW56.1, U2.13
ROW1: D1.1, D2.1, D3.1, D4.1, D5.1, D6.1, D7.1, D8.1, D9.1, D10.1, D11.1, U2.30
ROW2: D12.1, D13.1, D14.1, D15.1, D16.1, D17.1, D18.1, D19.1, D20.1, D21.1, D22.1, U2.29
ROW3: D23.1, D24.1, D25.1, D26.1, D27.1, D28.1, D29.1, D30.1, D31.1, D32.1, D33.1, U2.28
ROW4: D34.1, D35.1, D36.1, D37.1, D38.1, D39.1, D40.1, D41.1, D42.1, D43.1, D44.1, U2.27
ROW5: D45.1, D46.1, D47.1, D48.1, D49.1, D50.1, D51.1, D52.1, D53.1, D54.1, D55.1, U2.26
UART_RX: J2.2, U2.20
UART_TX: J2.3, U2.21

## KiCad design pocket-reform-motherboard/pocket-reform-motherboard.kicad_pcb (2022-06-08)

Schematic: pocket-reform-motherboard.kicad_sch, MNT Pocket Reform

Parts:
BT1: V364; BatteryHolder_Keystone_2998_1x6.8mm
C2, C4, C5, C6, C17, C39, C51, C56, C65, C67: 10uF; C_0603_1608Metric
C7, C8, C11, C12, C18, C19, C52, C58: 10nF; C_0603_1608Metric
C9, C10, C20, C26, C34, C36: 1uF; C_0603_1608Metric
C13: 12pF; C_0603_1608Metric
C14, C83, C123, C124, C126: 47uF; C_0603_1608Metric
C15, C16: 330uF; CP_Elec_6.3x5.4
C21, C23: 18pF; C_0603_1608Metric
C22, C24: 27pF; C_0603_1608Metric; LCSC C107045
C25, C27, C28, C29, C30, C31, C32, C33, C35, C38, C40, C41, C42, C43, C44, C45, C46, C47, C48, C49, C50, C53, C54, C55, C57, C59, C60, C61, C62, C63, C64, C66, C68, C69, C72, C73, C76, C77, C78, C85, C86, C87, C88, C89, C90, C91, C92, C93: 0.1uF; C_0603_1608Metric
C37: 1nF; C_0603_1608Metric
C82: 470nF; C_0603_1608Metric
D1: LED_MODEM; LED_0603_1608Metric
D2, D4, D5, D6: PMEG3050EP,115; D_SOD-128
D7: BZX84-C5V6,215; D_SOD-323
D8, D9: LED_Small; LED_0603_1608Metric
D10: 19-337/R6GHBHC-A01/2T; LED_19-337_R6GHBHC-A01_2T
D11: SS54?; D_SMA
D12: SD0603S040S0R2; D_0603_1608Metric
D23: LED_NVME; LED_0603_1608Metric
FB1: 220@100MHz 1.4A; L_0603_1608Metric
FB2, FB3, FB4, FB5, FB8, FB9, FB10: 100@100MHz 3A; L_0603_1608Metric
GFX1: MountingHole; pocket-reform
H1, H2, H3, H4: MountingHole_Pad; MountingHole_2.2mm_M2_DIN965_Pad
H5, H6, H7: NGFF-Mount1; WA-SMSI-M2
J1: CHARGER; JST_PH_S9B-PH-SM4-TB_1x09-1MP_P2.00mm_Horizontal
J2: DM3AT-SF-PEJM5; LCSC C114218
J3, J14: USB_C_Receptacle; USB_C_Receptacle_Amphenol_12401548E4-2A_CircularHoles
J4: 09452812561; Manufacturer_Part_Number 09452812561; Mouser Part Number 617-09452812561
J5: SYSCTL; JST_PH_S4B-PH-SM4-TB_1x04-1MP_P2.00mm_Horizontal
J6: USB_INT1; JST_PH_S4B-PH-SM4-TB_1x04-1MP_P2.00mm_Horizontal
J7: HDMI_D_1.4; HDMI_Micro-D_Molex_46765-0x01
J8: SIM_Card; MOLEX_78800-0001
J9: USB_C_Receptacle_USB2.0; USB_C_Receptacle_HRO_TYPE-C-31-M-12
J10: 1-2199230-6; TE_1-2199230-6
J11: Conn_01x33; Hirose_FH12-33S-0.5SH_1x33-1MP_P0.50mm_Horizontal
J12: 2199230-5; TE_2199230-5
J13: FH35C-31S-0.3HW(50); TE_3-2328724-1
J15: Conn_01x02; JST_GH_SM02B-GHS-TB_1x02-1MP_P1.25mm_Horizontal
J16, J17: Conn_01x03; PinHeader_1x03_P2.54mm_Vertical
L1: 22uH; L_Taiyo-Yuden_NR-30xx
L2: 2.2uH; L_1210_3225Metric
L3, L4: 15uH; L_Vishay_IHLP-4040
L5, L6: 15uH; L_Taiyo-Yuden_NR-30xx; LCSC C223122
MK1: MP23ABS1TR; MIC_MP23ABS1TR; PARTREV 5
R1, R29, R34, R36, R58, R60, R61, R110: 1k; R_0603_1608Metric
R4, R5, R9, R11, R12, R13, R44, R45, R46, R49, R50, R51, R67, R70, R71, R81, R83, R84, R101, R102, R103, R104, R105, R106, R107, R108, R109, R111: 0; R_0603_1608Metric
R6, R7, R8, R69, R87: 100k; R_0603_1608Metric
R10, R27, R55: 200k; R_0603_1608Metric
R14: 280k; R_0603_1608Metric
R15, R17, R22, R30, R32, R38, R52, R54, R56, R68, R75, R85, R96: 10k; R_0603_1608Metric
R16: 3.16k; R_0603_1608Metric
R18: 5.83k; R_0603_1608Metric
R19: 1.3M; R_0603_1608Metric
R20: 300k; R_0603_1608Metric
R21: 1M; R_0603_1608Metric
R23, R62, R63, R64: DNP; R_0603_1608Metric
R24, R25, R26, R89, R93: 4.7k; R_0603_1608Metric
R28: 120k; R_0603_1608Metric
R31, R33: 36k; R_0603_1608Metric
R35: 1k; R_0603_1608Metric; LCSC C105428
R37, R39, R40, R41: 75 1%; R_0603_1608Metric
R47, R48: 27.4; R_0603_1608Metric
R53: 12k 1%; R_0603_1608Metric
R57, R59: 4.7k; R_0603_1608Metric; LCSC C105428
R65, R66, R198, R199: 49.9; R_0603_1608Metric
R72: 2k2; R_0603_1608Metric
R76, R77, R79, R80, R82: 33; R_0603_1608Metric
R90: 27k; R_0603_1608Metric
R97, R98, R99, R100: 47k; R_0603_1608Metric
SW1: SW_DIP_x01; SW_DIP_SPSTx01_Slide_Omron_A6S-110x_W8.9mm_P2.54mm
SW2: RESET; SW_Push_1P1T_NO_CK_KMR2
TP1: PRTCTL1; TestPoint_Pad_D1.0mm
TP2: PRTCTL3; TestPoint_Pad_D1.0mm
TP3: PRTCTL2; TestPoint_Pad_D1.0mm
TP4: PRTCTL4; TestPoint_Pad_D1.0mm
TP5, TP6: TestPoint; TestPoint_Pad_D1.0mm; LCSC DNP
TR1: TG111-MSC13LF; Transformer_Ethernet_HALO_TG111-MSC13
U1: reform2-som-connector; TE_1473149-4
U2: MAX1837EUT33+T; SOT-23-6
U3: LM3674MFX-ADJ/NOPB; SOT-23-5
U4: TLV1117-18; SOT-223
U5, U6: TPS5450DDAR; TI_SO-PowerPAD-8_ThermalVias
U7: CN301; SOT-23-5
U8: RP2040; RP2040-QFN-56
U9: USB7002/KDX; QFN40P1200X1200X90-101N; PARTREV N/A
U10: W25Q32JVSS; SOIC-8_5.23x5.23mm_P1.27mm
U11: PCF8523T; SOIC-8_3.9x4.9mm_P1.27mm
U12: AP22815; SOT-23-5
U13: TXS0108EPW; TSSOP-20_4.4x6.5mm_P0.65mm
U14: SN74AVC1T45; SOT-23-6
U15, U16, U19, U20, U21, U22: TPD4E02B04DQA; USON-10_2.5x1.0mm_P0.5mm
U17: TPD12S521; TSSOP50P640X120-38N
U18: TLV320AIC3100; VQFN-32-1EP_5x5mm_P0.5mm_EP3.5x3.5mm
U23: FUSB302BMPX; WQFN-14-1EP_2.5x2.5mm_P0.5mm_EP1.45x1.45mm
Y1: 25MHz; Crystal_SMD_Abracon_ABM8G-4Pin_3.2x2.5mm
Y2: 12MHz 18pF; Crystal_SMD_3225-4Pin_3.2x2.5mm; LCSC C91749
Y3: 32.768 kHz; Crystal_SMD_3215-2Pin_3.2x1.5mm

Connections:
1V2_ENABLE: R8.1, R46.2, U3.3 (EN)
3V3_ENABLE: R7.1, R49.2, U6.5 (EN)
5V_ENABLE: R6.1, R51.2, U5.5 (EN)
+1V1: C26.1, C28.1, C30.1, U8.23 (DVDD), U8.45 (VREG_VOUT), U8.50 (DVDD)
+1V2: C13.1, C17.1, L2.2, R14.1, U9.9 (VDD12), U9.18 (VDD12), U9.25 (VDD12), U9.33 (VDD12), U9.41 (VDD12), U9.55 (VDD12), U9.78 (VDD12), U9.83 (VDD12), U9.93 (VDD12)
+1V8: C10.1, C56.1, C62.1, J13.31, R71.2, R81.2, U4.2 (VO), U18.3 (DVDD)
+3V3: C6.1, C16.1, C19.2, C69.2, C77.1, FB3.1, FB4.1, FB5.2, FB8.1, J13.1, J13.2, J13.3, J13.4, J13.26, J13.27, L4.2, MK1.5 (VDD), R4.2, R17.1, R22.1, R25.1, R29.1, R30.1, R31.1, R32.1, R33.1, R34.1, R52.2, R54.2, R85.1, R87.1, R90.1, R97.2, R98.2, R99.2, R100.2, U3.1 (Vin), U9.26 (VDD33), U9.44 (VDD33), U9.53 (VDD33), U9.62 (VDD33), U9.67 (VDD33), U9.79 (VDD33), U9.86 (VDD33), U9.99 (VDD33)
+5V: C15.1, C18.2, C40.1, C47.1, C73.2, D12.2 (A), FB1.1, FB2.1, J3.A4 (VBUS), J3.A9 (VBUS), J3.B4 (VBUS), J3.B9 (VBUS), L3.2, R11.1, R15.1, R62.2, R68.2, U1.1 (5V), U1.2 (5V), U1.3 (5V), U1.4 (5V), U1.5 (5V), U1.6 (5V), U8.48 (USB_VDD), U12.5 (IN), U17.1 (5V_SUPPLY)
/DP1_DISCHARGE: U9.46 (PF5)
/DP1_VCONN1: U9.49 (PF8)
/DP1_VCONN2: U9.50 (PF9)
/DP2_DISCHARGE: U9.45 (PF4)
/DP2_VCONN1: U9.51 (PF10)
/DP2_VCONN2: U9.52 (PF11)
/GPIO90: U9.75 (PF26)
/GPIO91: U9.76 (PF27)
/GPIO92: U9.77 (PF28)
/GPIO93: U9.74 (PF29)
/GPIO94: R54.1, U9.2 (PF30/VBUS_DET)
/GPIO95: U9.3 (PF31)
/M2_CLKREQn: J10.52
/M2_SMB_ALERTn: J10.44
/M2_SMB_CLK: J10.40
/M2_SMB_DATA: J10.42
/M_ANTCTL0: J12.59
/M_ANTCTL1: J12.61
/M_ANTCTL2: J12.58
/M_ANTCTL3: J12.56
/M_COEX1: J12.64
/M_COEX2: J12.62
/M_CONFIG_0: J12.21
/M_CONFIG_1: J12.69
/M_CONFIG_2: J12.75
/M_CONFIG_3: J12.1
/M_DPR: J12.25
/M_I2C_SCL: J12.38
/M_I2C_SDA: J12.68
/M_I2S_CLK: J12.20
/M_I2S_MCLK(IO): J12.60
/M_I2S_RX: J12.22
/M_I2S_TX: J12.24
/M_I2S_WA: J12.28
/M_LAA_TX_EN: J12.63
/M_SIM1_DET: J12.66
/M_SIM2_CLK: J12.44
/M_SIM2_DATA: J12.42
/M_SIM2_DET: J12.40
/M_SIM2_PWR: J12.48
/M_SIM2_RESET: J12.46
/M_VIO_1V8: J12.65
/PRT_CTL1: TP1.1, U9.60 (PF17)
/PRT_CTL2: TP3.1, U9.58 (PF15)
/PRT_CTL3: TP2.1, U9.59 (PF16)
/PRT_CTL4: TP4.1, U9.56 (PF13)
/RUD+: J9.A6 (D+), J9.B6 (D+), R47.2, R63.1
/RUD-: J9.A7 (D-), J9.B7 (D-), R48.2, R64.1
/U_GPIO70: U9.47 (PF6)
/U_GPIO71: U9.48 (PF7)
/U_GPIO76: U9.54 (PF12)
/U_GPIO78: U9.57 (PF14)
/U_M_I2C_CLK: U9.61 (PF18)
/U_M_I2C_DATA: U9.66 (PF19)
/U_SPI_CE_N: U9.69 (PF20/CFG_NON_REM)
/U_SPI_CLK: U9.68 (PF21)
/U_SPI_D0: R55.1, U9.70 (PF22/CFG_BC_EN)
/U_SPI_D1: U9.71 (PF23)
/U_SPI_D2: U9.72 (PF24)
/U_SPI_D3: U9.73 (PF25)
/~M_LED1: D1.1 (K), J12.10
/~M_PWROFF: J12.6
/~M_WOWWAN: J12.23
/~M_W_DISABLE1: J12.8
/~M_W_DISABLE2: J12.26
/~PCIE2_CLKREQ: J12.52
/~PCIE2_WAKE: J12.54
BACKLIGHT_EN: J13.6
BACKLIGHT_PWM: U1.164 (SPDIF_RX/PWM2)
DAC_BCLK: R76.1, U1.170 (SAI2_TXC)
DAC_DIN: R79.1, U1.166 (SAI2_RXD)
DAC_DOUT: R77.1, U1.178 (SAI2_TXD)
DAC_MCLK: R82.2, U1.176 (SAI2_MCLK)
DAC_RXFS: U1.168 (SAI2_RXFS)
DAC_SCL: U1.101 (I2C3_SCL), U11.6 (SCL), U18.10 (SCL)
DAC_SDA: U1.103 (I2C3_SDA), U11.5 (SDA), U18.9 (SDA)
DAC_TXFS: R80.1, U1.172 (SAI2_TXFS)
DISP_EN: J13.30
DISP_TE: J13.25
DSI_CLK_N: J11.19, J13.15
DSI_CLK_P: J11.20, J13.16
DSI_D0_N: J11.25, J13.12
DSI_D0_P: J11.26, J13.13
DSI_D1_N: J11.22, J13.18
DSI_D1_P: J11.23, J13.19
DSI_D2_N: J11.16, J13.21
DSI_D2_P: J11.17, J13.22
DSI_D3_N: J11.13, J13.9
DSI_D3_P: J11.14, J13.10
ETH0_A+: TR1.2 (TD1+), U1.29 (TRX0_P)
ETH0_A-: TR1.3 (TD1-), U1.27 (TRX0_N)
ETH0_B+: TR1.5 (TD2+), U1.23 (TRX1_P)
ETH0_B-: TR1.6 (TD2-), U1.21 (TRX1_N)
ETH0_C+: TR1.8 (TD3+), U1.17 (TRX2_P)
ETH0_C-: TR1.9 (TD3-), U1.15 (TRX2_N)
ETH0_D+: TR1.11 (TD4+), U1.11 (TRX3_P)
ETH0_D-: TR1.12 (TD4-), U1.9 (TRX3_N)
ETH0_DA+: J4.1, TR1.23 (MTX1+)
ETH0_DA-: J4.2, TR1.22 (MTX1-)
ETH0_DB+: J4.6, TR1.20 (MTX2+)
ETH0_DB-: J4.7, TR1.19 (MTX2-)
ETH0_DC+: J4.4, TR1.17 (MTX3+)
ETH0_DC-: J4.5, TR1.16 (MTX3-)
ETH0_DD+: J4.9, TR1.14 (MX4+)
ETH0_DD-: J4.10, TR1.13 (MX4-)
ETH0_LED_LINK1: D9.1 (K), U1.83 (JTAG_TDO)
ETH0_LED_RX: D8.1 (K), U1.79 (JTAG_MOD)
HDMI_AUXN: U1.189 (HDMI_AUX_N)
HDMI_AUXP: U1.187 (HDMI_AUX_P)
HDMI_CEC: R100.1, U1.197 (HDMI_CEC), U17.16 (CE_REMOTE_IN)
HDMI_CLKN: J7.14 (CK-), U1.163 (HDMI_CLK_N), U17.15 (TMDS_CK-), U17.24 (TMDS_CK-)
HDMI_CLKP: J7.12 (CK+), U1.165 (HDMI_CLK_P), U17.13 (TMDS_CK+), U17.26 (TMDS_CK+)
HDMI_HPD: R97.1, U1.199 (HDMI_HPD), U17.19 (HOTPLUG_DET_IN)
HDMI_SCL: R98.1, U1.195 (HDMI_DDC_SCL), U17.17 (DDC_CLK_IN)
HDMI_SDA: R99.1, U1.193 (HDMI_DDC_SDA), U17.18 (DDC_DAT_IN)
HDMI_TX0N: J7.11 (D0-), U1.169 (HDMI_TX0_N), U17.12 (TMDS_D0-), U17.27 (TMDS_D0-)
HDMI_TX0P: J7.9 (D0+), U1.171 (HDMI_TX0_P), U17.10 (TMDS_D0+), U17.29 (TMDS_D0+)
HDMI_TX1N: J7.8 (D1-), U1.175 (HDMI_TX1_N), U17.9 (TMDS_D1-), U17.30 (TMDS_D1-)
HDMI_TX1P: J7.6 (D1+), U1.177 (HDMI_TX1_P), U17.7 (TMDS_D1+), U17.32 (TMDS_D1+)
HDMI_TX2N: J7.5 (D2-), U1.181 (HDMI_TX2_N), U17.6 (TMDS_D2-), U17.33 (TMDS_D2-)
HDMI_TX2P: J7.3 (D2+), U1.183 (HDMI_TX2_P), U17.4 (TMDS_D2+), U17.35 (TMDS_D2+)
IMX_RESETn: U1.87 (EXT_RESET_N)
IMX_RTC_IRQ: R67.1, U1.141 (RTC_IRQ)
IMX_UART1_RX: J16.2, U1.126 (UART1_RXD)
IMX_UART1_TX: J16.1, U1.128 (UART1_TXD)
IMX_UART2_RX: J17.2, U1.122 (UART2_RXD)
IMX_UART2_TX: J17.1, U1.124 (UART2_TXD)
IMX_WAKE: R45.2, U1.145 (GPIO1_IO3)
LPC_MISO: R50.2, U1.93 (ECSPI2_MISO)
LPC_MOSI: R44.2, U1.91 (ECSPI2_MOSI)
LPC_SCK: U1.97 (ECSPI2_SCLK), U8.13 (GPIO10)
LPC_SS0: U1.89 (ECSPI2_SS0), U8.12 (GPIO9)
M2B_RST: J12.67
unnamed: BT1.1 (+), U11.3 (VBAT)
unnamed: C9.1, R4.1, U4.3 (VI)
unnamed: C11.1, U5.1 (BOOT)
unnamed: C11.2, D5.1 (K), L3.1, U5.8 (PH)
unnamed: C12.1, U6.1 (BOOT)
unnamed: C12.2, D6.1 (K), L4.1, U6.8 (PH)
unnamed: C13.2, R10.1, R14.2, U3.4 (FB)
unnamed: C20.1, D7.1 (K), R21.1, U7.2 (VCC)
unnamed: C21.1, U9.97 (XTALO), Y1.1
unnamed: C22.1, U8.20 (XIN), Y2.1
unnamed: C23.1, U9.98 (XTALI/CLK_IN), Y1.3
unnamed: C24.1, R35.1, Y2.3
unnamed: C37.1, R37.2, R39.2, R40.2, R41.2
unnamed: C39.1, C41.1, FB1.2, J6.1
unnamed: C42.1, TR1.1 (TCT1)
unnamed: C43.1, TR1.4 (TCT2)
unnamed: C44.1, TR1.7 (TCT3)
unnamed: C45.1, TR1.10 (TCT4)
unnamed: C48.1, C49.1, R75.1, R81.1, U13.2 (VCCA), U14.1 (VCCA)
unnamed: C50.1, C51.1, FB5.1, U18.17 (AVDD), U18.28 (HPVDD)
unnamed: C57.1, C67.1, FB2.2, U18.21 (SPKVDD), U18.24 (SPKVDD)
unnamed: C63.1, C64.1, C65.1, C66.1, FB8.2, J2.4 (VDD), U13.19 (VCCB), U14.6 (VCCB)
unnamed: C68.1, U18.14 (MIC1RP)
unnamed: C68.2, MK1.1 (OUT), R72.2, U18.11 (VOL/MICDET)
unnamed: C72.2, U17.37 (ESD_BYP)
unnamed: C76.1, C82.1, J15.1, L5.2
unnamed: C78.1, C82.2, J15.2, L6.2
unnamed: C85.1, J3.A3 (TX1-), U20.4 (IO3)
unnamed: C86.1, J3.B3 (TX2-), U22.4 (IO3)
unnamed: C87.1, J7.19 (+5V), U17.38 (5V_OUT)
unnamed: C88.1, J3.A2 (TX1+), U20.5 (IO4)
unnamed: C89.1, J3.B2 (TX2+), U22.5 (IO4)
unnamed: C90.1, J14.A3 (TX1-), U19.4 (IO3)
unnamed: C91.1, J14.B3 (TX2-), U21.4 (IO3)
unnamed: C92.1, J14.A2 (TX1+), U19.5 (IO4)
unnamed: C93.1, J14.B2 (TX2+), U21.5 (IO4)
unnamed: C52.1, C53.1, C54.1, C55.1, C83.1, C123.1, FB3.2, J12.2, J12.4, J12.70, J12.72, J12.74, R1.1
unnamed: C58.1, C59.1, C60.1, C61.1, C124.1, C126.1, FB4.2, J10.2, J10.4, J10.12, J10.14, J10.16, J10.18, J10.70, J10.72, J10.74, R110.1
unnamed: D1.2 (A), R1.2
unnamed: D4.1 (K), L1.1, U2.4 (LX)
unnamed: D8.2 (A), R29.2
unnamed: D9.2 (A), R34.2
unnamed: D10.4 (BA), R61.2
unnamed: D10.5 (GA), R60.2
unnamed: D10.6 (RA), R58.2
unnamed: D12.1 (K), R89.1, R93.1
unnamed: D23.1 (K), J10.10
unnamed: D23.2 (A), R110.2
unnamed: FB9.1, U18.22 (SPKP), U18.26 (SPKP)
unnamed: FB9.2, L5.1
unnamed: FB10.1, U18.19 (SPKM), U18.23 (SPKM)
unnamed: FB10.2, L6.1
unnamed: J2.1 (DAT2), U13.20 (B1)
unnamed: J2.2 (DAT3/CD), U13.18 (B2)
unnamed: J2.3 (CMD), U13.14 (B6)
unnamed: J2.5 (CLK), U14.4 (B)
unnamed: J2.7 (DAT0), U13.13 (B7)
unnamed: J2.8 (DAT1), U13.12 (B8)
unnamed: J3.A5 (CC1), R83.1, U16.1 (IO1)
unnamed: J3.B5 (CC2), R84.1, U16.2 (IO2)
unnamed: J7.1 (HPD/HEAC-), R96.1, U17.20 (HOTPLUG_DET_OUT)
unnamed: J7.15 (CEC), R90.2, U17.23 (CE_REMOTE_OUT)
unnamed: J7.17 (SCL), R89.2, U17.22 (DDC_CLK_OUT)
unnamed: J7.18 (SDA), R93.2, U17.21 (DDC_DAT_OUT)
unnamed: J9.A4 (VBUS), J9.A9 (VBUS), J9.B4 (VBUS), J9.B9 (VBUS), R62.1
unnamed: J10.11, R107.1
unnamed: J10.13, R104.1
unnamed: J10.23, R108.1
unnamed: J10.25, R105.1
unnamed: J10.35, R109.1
unnamed: J10.37, R106.1
unnamed: J14.A5 (CC1), R101.2, R111.1, U15.1 (IO1)
unnamed: J14.B5 (CC2), R102.2, R103.1, U15.2 (IO2)
unnamed: L2.1, U3.5 (SW)
unnamed: R5.1, U9.1 (RESET_N)
unnamed: R9.1, U2.1 (FB)
unnamed: R11.2, U1.118 (USB1_VBUS)
unnamed: R12.2, U1.30 (UART3_TXD)
unnamed: R13.1, U1.32 (UART3_RXD)
unnamed: R15.2, R16.1, U5.4 (VSENSE)
unnamed: R17.2, R18.1, U6.4 (VSENSE)
unnamed: R19.1, R20.2, U7.4 (LBI)
unnamed: R22.2, R23.1, U9.21 (CFG_STRAP1)
unnamed: R24.1, U9.64 (TEST2)
unnamed: R25.2, U9.63 (TEST1)
unnamed: R26.1, U9.65 (TEST3)
unnamed: R27.1, U9.22 (CFG_STRAP2)
unnamed: R30.2, U9.4 (DP1_VBUS_MON)
unnamed: R31.2, U9.87 (CC1_UP)
unnamed: R32.2, U9.36 (DP2_VBUS_MON)
unnamed: R33.2, U9.88 (CC2_UP)
unnamed: R35.2, U8.21 (XOUT)
unnamed: R37.1, TR1.15 (MCT4)
unnamed: R39.1, TR1.18 (MCT3)
unnamed: R40.1, TR1.21 (MCT2)
unnamed: R41.1, TR1.24 (MTC1)
unnamed: R44.1, U8.11 (GPIO8)
unnamed: R45.1, U8.30 (GPIO19)
unnamed: R46.1, U8.35 (GPIO23)
unnamed: R47.1, U8.47 (USB_DP)
unnamed: R48.1, U8.46 (USB_DM)
unnamed: R49.1, U8.36 (GPIO24)
unnamed: R50.1, U8.14 (GPIO11)
unnamed: R51.1, U8.37 (GPIO25)
unnamed: R52.1, U9.80 (VBUS_MON_UP)
unnamed: R53.1, U9.100 (RBIAS)
unnamed: R58.1, U8.28 (GPIO17)
unnamed: R60.1, U8.27 (GPIO16)
unnamed: R61.1, U8.18 (GPIO15)
unnamed: R67.2, U11.7 (~INT1/CLKOUT)
unnamed: R68.1, U12.3 (FLG)
unnamed: R70.1, U18.31 (~RESET)
unnamed: R71.1, U18.2 (IOVDD)
unnamed: R72.1, U18.12 (MICBIAS)
unnamed: R75.2, U13.10 (OE), U14.5 (DIR)
unnamed: R76.2, U18.7 (BCLK)
unnamed: R77.2, U18.5 (DIN)
unnamed: R79.2, U18.4 (DOUT)
unnamed: R80.2, U18.6 (WCLK)
unnamed: R82.1, U18.8 (MCLK)
unnamed: R85.2, U17.2 (LV_SUPPLY)
unnamed: R103.2, U23.1 (CC2), U23.14 (CC2)
unnamed: R111.2, U23.10 (CC1), U23.11 (CC1)
unnamed: U11.1 (OSCI), Y3.1
unnamed: U11.2 (OSCO), Y3.2
PCIE1_CLK_N: J10.53, R199.2, U1.60 (PCIE1_REFCLK_N)
PCIE1_CLK_P: J10.55, R198.2, U1.58 (PCIE1_REFCLK_P)
PCIE1_RESETn: J10.50, U1.37 (PCIE_RST_B)
PCIE1_RXN: U1.54 (PCIE1_RX_N)
PCIE1_RXP: U1.52 (PCIE1_RX_P)
PCIE1_RX_N: J10.41
PCIE1_RX_P: J10.43
PCIE1_TXN: U1.48 (PCIE1_TX_N)
PCIE1_TXP: U1.46 (PCIE1_TX_P)
PCIE1_TX_N: J10.47
PCIE1_TX_P: J10.49
PCIE2_CLK_N: J12.53, R65.2, U1.66 (PCIE2_REFCLK_N)
PCIE2_CLK_P: J12.55, R66.2, U1.64 (PCIE2_REFCLK_P)
PCIE2_RESETn: J12.50, U1.24 (WIFI_RESET)
PCIE2_RX_N: J12.47, U1.78 (PCIE2_RX_N)
PCIE2_RX_P: J12.49, U1.76 (PCIE2_RX_P)
PCIE2_TX_N: J12.41, U1.72 (PCIE2_TX_N)
PCIE2_TX_P: J12.43, U1.70 (PCIE2_TX_P)
PROG: R36.1, SW1.1
QSPI_CS: R36.2, R38.2, U8.56 (QSPI_SS), U10.1 (~CS)
QSPI_SCK: U8.52 (QSPI_SCLK), U10.6 (CLK)
QSPI_SD0: U8.53 (QSPI_SD0), U10.5 (DI(IO0))
QSPI_SD1: U8.55 (QSPI_SD1), U10.2 (DO(IO1))
QSPI_SD2: U8.54 (QSPI_SD2), U10.3 (IO2)
QSPI_SD3: U8.51 (QSPI_SD3), U10.7 (IO3)
RESET: R56.2, SW2.1 (A), U8.26 (RUN)
RP_FUSB_INT: U8.17 (GPIO14), U23.5 (INT_N)
RP_SCL0: J1.7, R57.1, U8.3 (GPIO1), U23.6 (SCL)
RP_SDA0: J1.6, R59.1, U8.2 (GPIO0), U23.7 (SDA)
RP_UART1_RX: J5.3, U8.7 (GPIO5)
RP_UART1_TX: J5.2, U8.6 (GPIO4)
RP_UART2_RX: R12.1, U8.16 (GPIO13)
RP_UART2_TX: R13.2, U8.15 (GPIO12)
SD_CLK: U1.22 (SD2_CLK), U14.3 (A)
SD_CMD: U1.20 (SD2_CMD), U13.7 (A6)
SD_D0: U1.12 (SD2_DATA0), U13.8 (A7)
SD_D1: U1.14 (SD2_DATA1), U13.9 (A8)
SD_D2: U1.16 (SD2_DATA2), U13.1 (A1)
SD_D3: U1.18 (SD2_DATA3), U13.3 (A2)
SD_DET: J2.9 (DET_B), R87.2, U1.26 (SD2_CD)
STANDBY_3V3: C14.1, C25.1, C27.1, C29.1, C31.1, C32.1, C33.1, C34.1, C35.1, C36.1, C38.1, C46.2, J1.5, J5.1, L1.2, R38.1, R56.1, R57.2, R59.2, U2.6 (OUT), U8.1 (IOVDD), U8.10 (IOVDD), U8.22 (IOVDD), U8.33 (IOVDD), U8.42 (IOVDD), U8.43 (ADC_AVDD), U8.44 (VREG_IN), U8.49 (IOVDD), U10.8 (VCC), U11.8 (VDD), U23.3 (VDD), U23.4 (VDD)
SWC: TP6.1, U8.24 (SWCLK)
SWD: TP5.1, U8.25 (SWD)
UIM_CLK: J8.3 (CLK), J12.32
UIM_IO: J8.7 (I/O), J12.34
UIM_PWR: J8.1 (VCC), J12.36
UIM_RST: J8.2 (RST), J12.30
UIM_VPP: J8.6 (VPP)
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

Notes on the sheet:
Temp monitor?
Power Rails
These are OK, unclear why inconsistent pin numbering in symbol
Backlight is digitally controlled
consider: ANX7580 eDP -> DSI to integrate LS1028A
PERp1
PETp1
or: ON SEMI NCV1117ST18T3G
PERp3
TODO: decouple
TODO: voltages!
SSD M.2 Card Slot
LM3674MFX-1.2/NOPB
Realtime Clock
Optional 1Gb Ethernet
MIPI-DSI / Display Connector
TODO
SOURCE
GPIO43
TODO: we could supply 5V on VCONN
Keystone 2998 C238096
works only with NXP: optional internal USB connection RP/IMX
UART to KBD
Charger Interface
TODO: confirm
PERn2
TODO: confirm pinout!
TODO: Shield?
JDI LT070ME05000
PETp3
1.25mm pitch Molex Picoblade JST GH?
Power to charger
Status LED
disable battery charging
or: Heling MT24-S1T1
USB Hub
4.5-24V
M Key 42H M.2
PERp2
iX Industrial 10B-1

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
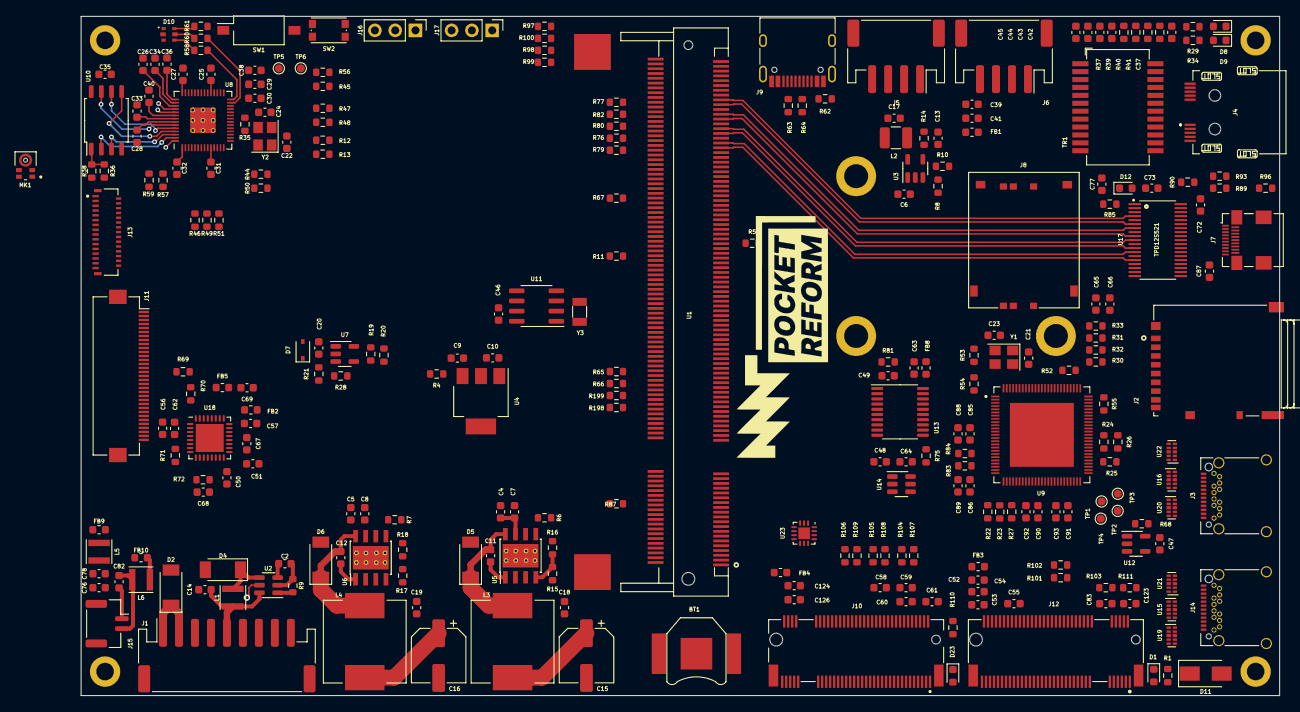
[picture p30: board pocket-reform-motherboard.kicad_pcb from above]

Board: 6 copper layers, 150.0 x 85.0 mm, 274 parts (0 on the bottom side), 284 nets.

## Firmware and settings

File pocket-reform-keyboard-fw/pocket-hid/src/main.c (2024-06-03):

/*
  SPDX-License-Identifier: GPL-3.0-or-later
  MNT Pocket Reform Keyboard/Trackball Controller Firmware for RP2040
  Copyright 2021-2024 MNT Research GmbH (mntre.com)

  TinyUSB callbacks/code based on code
  Copyright 2019 Ha Thach (tinyusb.org)
*/

#include <stdlib.h>
#include <stdio.h>
#include <string.h>

#include "bsp/board_api.h"
#include "tusb.h"

#include "pico/stdlib.h"
#include "pico/binary_info.h"
#include "pico/multicore.h"
#include "hardware/gpio.h"
#include "hardware/i2c.h"
#include "hardware/irq.h"

#include "usb_descriptors.h"
#include "oled.h"
#include "menu.h"
#include "remote.h"
#include "keyboard.h"

#include "ws2812.pio.h"

#define KBD_VARIANT_QWERTY_US
#define KBD_COLS 12
#define KBD_ROWS 6
#define KBD_MATRIX_SZ KBD_COLS * KBD_ROWS + 4

#include "matrix.h"

#define PIN_SDA 0
#define PIN_SCL 1

#define PIN_UART_TX 4
#define PIN_UART_RX 5

#define PIN_ROW1 19
#define PIN_ROW2 20
#define PIN_ROW3 23
#define PIN_ROW4 22
#define PIN_ROW5 21
#define PIN_ROW6 18

#define PIN_COL1 6
#define PIN_COL2 7
#define PIN_COL3 8
#define PIN_COL4 9
#define PIN_COL5 10
#define PIN_COL6 11
#define PIN_COL7 12
#define PIN_COL8 13
#define PIN_COL9 14
#define PIN_COL10 15
#define PIN_COL11 16
#define PIN_COL12 17

#define PIN_LEDS 24

#define ADDR_SENSOR (0x79)

#define MAX_SCANCODES 6
static uint8_t pressed_scancodes[MAX_SCANCODES] = {0,0,0,0,0,0};
static int pressed_keys = 0;
static volatile uint32_t led_value = 0;

void hid_task(void);
int process_keyboard(uint8_t* resulting_scancodes);

#define UART_ID uart1
#define BAUD_RATE 115200
#define DATA_BITS 8
#define STOP_BITS 1
#define PARITY    UART_PARITY_NONE

// can be used as a global clock, incrementing around every ~10ms
static int hid_task_counter = 0;

int main(void)
{
  board_init();

  set_sys_clock_48mhz();

  tusb_init();

  uart_init(UART_ID, BAUD_RATE);
  uart_set_format(UART_ID, DATA_BITS, STOP_BITS, PARITY);
  uart_set_hw_flow(UART_ID, false, false);
  uart_set_fifo_enabled(UART_ID, true);
  gpio_set_function(PIN_UART_TX, GPIO_FUNC_UART);
  gpio_set_function(PIN_UART_RX, GPIO_FUNC_UART);
  unsigned int UART_IRQ = UART_ID == uart0 ? UART0_IRQ : UART1_IRQ;

  gpio_init(PIN_LEDS);
  gpio_set_dir(PIN_LEDS, true); // output

  gpio_init(PIN_COL1);
  gpio_set_dir(PIN_COL1, true);
  gpio_init(PIN_COL2);
  gpio_set_dir(PIN_COL2, true);
  gpio_init(PIN_COL3);
  gpio_set_dir(PIN_COL3, true);
  gpio_init(PIN_COL4);
  gpio_set_dir(PIN_COL4, true);
  gpio_init(PIN_COL5);
  gpio_set_dir(PIN_COL5, true);
  gpio_init(PIN_COL6);
  gpio_set_dir(PIN_COL6, true);
  gpio_init(PIN_COL7);
  gpio_set_dir(PIN_COL7, true);
  gpio_init(PIN_COL8);
  gpio_set_dir(PIN_COL8, true);
  gpio_init(PIN_COL9);
  gpio_set_dir(PIN_COL9, true);
  gpio_init(PIN_COL10);
  gpio_set_dir(PIN_COL10, true);
  gpio_init(PIN_COL11);
  gpio_set_dir(PIN_COL11, true);
  gpio_init(PIN_COL12);
  gpio_set_dir(PIN_COL12, true);

  gpio_init(PIN_ROW1);
  gpio_set_dir(PIN_ROW1, false);
  gpio_pull_down(PIN_ROW1);
  gpio_init(PIN_ROW2);
  gpio_set_dir(PIN_ROW2, false);
  gpio_pull_down(PIN_ROW2);
  gpio_init(PIN_ROW3);
  gpio_set_dir(PIN_ROW3, false);
  gpio_pull_down(PIN_ROW3);
  gpio_init(PIN_ROW4);
  gpio_set_dir(PIN_ROW4, false);
  gpio_pull_down(PIN_ROW4);
  gpio_init(PIN_ROW5);
  gpio_set_dir(PIN_ROW5, false);
  gpio_pull_down(PIN_ROW5);
  gpio_init(PIN_ROW6);
  gpio_set_dir(PIN_ROW6, false);
  gpio_pull_down(PIN_ROW6);

  i2c_init(i2c0, 100 * 1000);
  gpio_set_function(PIN_SDA, GPIO_FUNC_I2C);
  gpio_set_function(PIN_SCL, GPIO_FUNC_I2C);

  bi_decl(bi_2pins_with_func(PIN_SDA, PIN_SCL, GPIO_FUNC_I2C));

  unsigned char buf[] = {0x7f, 0x00, 0x00, 0x00};
  i2c_write_blocking(i2c0, ADDR_SENSOR, buf, 2, false);

  buf[0] = 0x05;
  buf[1] = 0x01;
  i2c_write_blocking(i2c0, ADDR_SENSOR, buf, 2, false);

  PIO pio = pio0;
  uint sm = 0;
  uint offset = pio_add_program(pio, &ws2812_program);

  ws2812_program_init(pio, sm, offset, PIN_LEDS, 800000, false);

  led_set_brightness(0x0);

  gfx_init(false);
  //anim_hello();

  irq_set_exclusive_handler(UART_IRQ, remote_on_uart_rx);
  irq_set_enabled(UART_IRQ, true);
  // bool rx_has_data, bool tx_needs_data
  uart_set_irq_enables(UART_ID, true, false);

  while (1) {
    pressed_keys = process_keyboard(pressed_scancodes);
    tud_task(); // tinyusb device task
    hid_task();
  }

  return 0;
}

//--------------------------------------------------------------------+
// Device callbacks
//--------------------------------------------------------------------+

// Invoked when device is mounted
void tud_mount_cb(void)
{
  // called
}

// Invoked when device is unmounted
void tud_umount_cb(void)
{
  // never called
}

// Invoked when usb bus is suspended
// remote_wakeup_en : if host allow us  to perform remote wakeup
// Within 7ms, device must draw an average of current less than 2.5 mA from bus
void tud_suspend_cb(bool remote_wakeup_en)
{
  // never called
  (void) remote_wakeup_en;
}

// Invoked when usb bus is resumed
void tud_resume_cb(void)
{
  // never called
}

// RGB LEDS

int __attribute__((optimize("Os"))) delay300ns() {
  // ~300ns
  asm volatile(
               "mov  r0, #9\n"    		// 1 cycle (was 10)
               "loop1: sub  r0, r0, #1\n"	// 1 cycle
               "bne   loop1\n"          	// 2 cycles if loop taken, 1 if not
               );
  return 0;
}

//--------------------------------------------------------------------+
// USB HID
//--------------------------------------------------------------------+

typedef struct TU_ATTR_PACKED
{
  uint8_t buttons; /**< buttons mask for currently pressed buttons in the mouse. */
  int8_t  x;       /**< Current delta x movement of the mouse. */
  int8_t  y;       /**< Current delta y movement on the mouse. */
  int8_t  wheel;   /**< Current delta wheel movement on the mouse. */
  int8_t  pan;     // using AC Pan
} hid_trackball_report_t;

bool tud_hid_trackball_report(uint8_t report_id,
                            uint8_t buttons, int8_t x, int8_t y, int8_t vertical, int8_t horizontal)
{
  hid_trackball_report_t report =
  {
    .buttons = buttons,
    .x       = x,
    .y       = y,
    .wheel   = vertical,
    .pan     = horizontal
  };

  return tud_hid_report(report_id, &report, sizeof(report));
}

uint8_t matrix_debounce[KBD_COLS*KBD_ROWS];
uint8_t matrix_state[KBD_COLS*KBD_ROWS];

int active_menu_mode = 0;
uint8_t last_menu_key = 0;
uint32_t hyper_enter_long_press_start_ms = 0;

uint8_t* active_matrix = matrix;
bool media_toggle = 0;
bool hyper_key = 0; // Am I holding HYPER?

// enter the menu
void enter_menu_mode(void) {
  active_menu_mode = 1;
  reset_and_render_menu();
}

void exit_menu_mode(void) {
  active_menu_mode = 0;
}

void reset_keyboard_state(void) {
  for (int i = 0; i < KBD_COLS*KBD_ROWS; i++) {
    matrix_debounce[i] = 0;
    matrix_state[i] = 0;
  }
  last_menu_key = 0;
  reset_menu();
}

int process_keyboard(uint8_t* resulting_scancodes) {
  // how many keys are pressed this round
  uint8_t total_pressed = 0;
  uint8_t used_key_codes = 0;

  for (int i=0; i<MAX_SCANCODES; i++) {
    pressed_scancodes[i] = 0;
  }

  for (int x = 0; x < KBD_COLS; x++) {
    gpio_put(PIN_COL1, 0);
    gpio_put(PIN_COL2, 0);
    gpio_put(PIN_COL3, 0);
    gpio_put(PIN_COL4, 0);
    gpio_put(PIN_COL5, 0);
    gpio_put(PIN_COL6, 0);
    gpio_put(PIN_COL7, 0);
    gpio_put(PIN_COL8, 0);
    gpio_put(PIN_COL9, 0);
    gpio_put(PIN_COL10, 0);
    gpio_put(PIN_COL11, 0);
    gpio_put(PIN_COL12, 0);

    switch (x) {
    case 0: gpio_put(PIN_COL1, 1); break;
    case 1: gpio_put(PIN_COL2, 1); break;
    case 2: gpio_put(PIN_COL3, 1); break;
    case 3: gpio_put(PIN_COL4, 1); break;
    case 4: gpio_put(PIN_COL5, 1); break;
    case 5: gpio_put(PIN_COL6, 1); break;
    case 6: gpio_put(PIN_COL7, 1); break;
    case 7: gpio_put(PIN_COL8, 1); break;
    case 8: gpio_put(PIN_COL9, 1); break;
    case 9: gpio_put(PIN_COL10, 1); break;
    case 10: gpio_put(PIN_COL11, 1); break;
    case 11: gpio_put(PIN_COL12, 1); break;
    }

    // wait for signal to stabilize
    //_delay_us(10);
    sleep_us(1);

    for (int y = 0; y < KBD_ROWS; y++) {
      uint8_t keycode;
      int loc = y*KBD_COLS+x;
      keycode = active_matrix[loc];
      uint8_t  pressed = 0;
      uint8_t  debounced_pressed = 0;

      switch (y) {
      case 0:  pressed = gpio_get(PIN_ROW1); break;
      case 1:  pressed = gpio_get(PIN_ROW2); break;
      case 2:  pressed = gpio_get(PIN_ROW3); break;
      case 3:  pressed = gpio_get(PIN_ROW4); break;
      case 4:  pressed = gpio_get(PIN_ROW5); break;
      case 5:  pressed = gpio_get(PIN_ROW6); break;
      }

      // shift new state as bit into debounce "register"
      matrix_debounce[loc] = (uint8_t)(matrix_debounce[loc]<<1)|pressed;

      // if unclear state, we need to keep the last state of the key
      if (matrix_debounce[loc] == 0x00) {
        matrix_state[loc] = 0;
      } else if (matrix_debounce[loc] == 0x01) {
        matrix_state[loc] = 1;
      }
      debounced_pressed = matrix_state[loc];

      if (debounced_pressed) {
        total_pressed++;

        // hyper + enter? open OLED menu
        if (keycode == KEY_ENTER && hyper_key) {
          if (!last_menu_key) {
            if (!active_menu_mode) {
              enter_menu_mode();
            }
            uint32_t now_ms = board_millis();
            if (!now_ms) now_ms++;

            if (!hyper_enter_long_press_start_ms) {
              hyper_enter_long_press_start_ms = now_ms;
              // edge case
            }
            if (now_ms - hyper_enter_long_press_start_ms > 1000) {
              // turn on computer after 2 seconds of holding hyper + enter
              execute_menu_function(KEY_1);
              exit_menu_mode();
              last_menu_key = KEY_1;
              hyper_enter_long_press_start_ms = 0;
            }
          }
        } else if (keycode == KEY_F12) {
          remote_wake_som();
        } else if (keycode == KEY_COMPOSE) {
          hyper_key = 1;
          active_matrix = matrix_fn;
        } else {
          if (active_menu_mode) {
            // not holding the same key?
            if (last_menu_key != keycode) {
              // hyper/menu functions
              int stay_menu = execute_menu_function(keycode);
              // don't repeat action while key is held down
              last_menu_key = keycode;

              // exit menu mode
              if (!stay_menu) {
                exit_menu_mode();
              }

              // after wake-up from sleep mode, skip further keymap processing
              if (stay_menu == 2) {
                reset_keyboard_state();
                enter_menu_mode();
                return 0;
              }
            }
          } else if (!last_menu_key) {
            // not menu mode, regular key: report keypress via USB
            // 6 keys is the limit in the HID descriptor
            if (used_key_codes < MAX_SCANCODES && resulting_scancodes && y < 5) {
              resulting_scancodes[used_key_codes++] = keycode;
            }
          }
        }
      } else {
        // key not pressed
        if (keycode == KEY_COMPOSE) {
          hyper_key = 0;
          active_matrix = matrix;
          hyper_enter_long_press_start_ms = 0;
        } else if (keycode == KEY_ENTER) {
          hyper_enter_long_press_start_ms = 0;
        }
      }
    }
  }

  // if no more keys are held down, allow a new menu command
  if (total_pressed<1) last_menu_key = 0;

  // if device is off and user is pressing random keys,
  // show a hint for turning on the device
  if (!remote_get_power_state()) {
    if (total_pressed>0 && !active_menu_mode && !hyper_key && !last_menu_key) {
      execute_menu_function(KEY_H);
    }
  }

  return used_key_codes;
}


int prev_buttons = 0;
int scroll_toggle = 0;
int prev_num_keys = 0;

int8_t tb_nx = 0;
int8_t tb_ny = 0;
int tb_btn_left = 0;
int tb_btn_right = 0;
int tb_btn_scroll = 0;
int tb_btn_middle = 0;
// TODO: implement HID commands to update these
int tb_btn_left_idx = KBD_COLS*5+4;
int tb_btn_right_idx = KBD_COLS*5+8;
int tb_btn_scroll_idx = KBD_COLS*5+7;
int tb_btn_middle_idx = KBD_COLS*5+3;

// returns motion yes/no
static int poll_trackball()
{
  tb_btn_left = matrix_state[tb_btn_left_idx]>0;
  tb_btn_middle = matrix_state[tb_btn_middle_idx]>0;
  tb_btn_right = matrix_state[tb_btn_right_idx]>0;
  tb_btn_scroll = matrix_state[tb_btn_scroll_idx]>0;

  uint8_t buf[] = {0x7f, 0x00, 0x00, 0x00};

  buf[0] = 0x02;

  i2c_write_blocking_until(i2c0, ADDR_SENSOR, buf, 1, true, make_timeout_time_ms(2));
  i2c_read_blocking_until(i2c0, ADDR_SENSOR, buf, 1, false, make_timeout_time_ms(2));

  if (buf[0] & 0xf0) {
    buf[0] = 0x03;
    i2c_write_blocking_until(i2c0, ADDR_SENSOR, buf, 1, true, make_timeout_time_ms(2));
    i2c_read_blocking_until(i2c0, ADDR_SENSOR, buf, 2, false, make_timeout_time_ms(2));

    tb_nx = (int8_t)buf[0];
    tb_ny = (int8_t)buf[1];

    // backlight hue/value wheel
    if (matrix_state[KBD_COLS*4+0]) {
      if (tb_ny) {
        // shift held? saturation
        if (matrix_state[KBD_COLS*3+0]) {
          led_mod_saturation(tb_ny);
        } else {
          led_mod_brightness(tb_ny);
        }
      }
      if (tb_nx) {
        led_mod_hue(tb_nx);
      }
    }

    return 1;
  }
  return 0;
}

static void send_hid_report(uint8_t report_id)
{
  // skip if hid is not ready yet
  if (!tud_hid_ready()) return;

  switch (report_id) {
    case REPORT_ID_KEYBOARD:
    {
      tud_hid_keyboard_report(REPORT_ID_KEYBOARD, 0, pressed_scancodes);
      prev_num_keys = pressed_keys;
    }
    break;

    case REPORT_ID_MOUSE:
    {
      int buttons = tb_btn_left | (tb_btn_right<<1) | (tb_btn_middle<<2);
      int motion = poll_trackball();

      if (motion) {
        // no button, right + down, no scroll pan
        if (tb_btn_scroll || scroll_toggle) {
          tud_hid_mouse_report(REPORT_ID_MOUSE, (uint8_t)buttons, 0, 0, 2*tb_ny, -2*tb_nx);
        } else {
          tud_hid_mouse_report(REPORT_ID_MOUSE, (uint8_t)buttons, -2*tb_nx, -2*tb_ny, 0, 0);
        }
      } else {
        if (tb_btn_middle && tb_btn_scroll) {
          // enter sticky scroll mode
          scroll_toggle = 1;
        } else {
          if (tb_btn_middle && scroll_toggle) {
            // exit sticky scroll mode
            scroll_toggle = 0;
          } else {
            // actually report the buttons
            tud_hid_mouse_report(REPORT_ID_MOUSE, (uint8_t)buttons, 0, 0, 0, 0);
          }
        }
      }

      prev_buttons = buttons;
    }
    break;

    case REPORT_ID_CONSUMER_CONTROL:
    {
      // use to avoid send multiple consecutive zero report
      /*static bool has_consumer_key = false;

      if ( btn )
      {
        // volume down
        uint16_t volume_down = HID_USAGE_CONSUMER_VOLUME_DECREMENT;
        tud_hid_report(REPORT_ID_CONSUMER_CONTROL, &volume_down, 2);
        has_consumer_key = true;
      }else
      {
        // send empty key report (release key) if previously has key pressed
        uint16_t empty_key = 0;
        if (has_consumer_key) tud_hid_report(REPORT_ID_CONSUMER_CONTROL, &empty_key, 2);
        has_consumer_key = false;
        }*/
    }
    break;

    case REPORT_ID_GAMEPAD:
    {
      // TODO: later
    }
    break;

    default: break;
  }
}

void led_task(uint32_t color) {
  uint32_t pixel_grb = color;

  for (int y=0; y<6; y++) {
    int w = 12;
    if (y==5) w = 4;
    for (int x=0; x<w; x++) {
      pio_sm_put_blocking(pio0, 0, pixel_grb << 8u);
    }
  }
}

uint8_t led_rgb_buf[12*3*6];

void led_bitmap(uint8_t row, const uint8_t* row_rgb) {
  // row = 5 -> commit
  if (row > 5) return;

  uint8_t* store = &led_rgb_buf[row*3*12];
  int offset = 0;
  for (int x=0; x<3*12; x++) {
    if (row == 5 && x == 0*3) offset = 3*3;
    if (row == 5 && x == 2*3) offset = 7*3;
    store[x] = row_rgb[x+offset];
    if (row == 5 && x == 4*3) break;
  }

  if (row == 5) {
    for (int y=0; y<6; y++) {
      int w = 12;
      if (y==5) w = 4;
      uint8_t* bitmap = &led_rgb_buf[y*3*12];
      for (int x=0; x<w; x++) {
        uint32_t pixel_grb = (bitmap[1]<<16u) | (bitmap[2]<<8u) | bitmap[0];
        pio_sm_put_blocking(pio0, 0, pixel_grb << 8u);
        bitmap+=3;
      }
    }
  }
}


// Every 10ms, we will sent 1 report for each HID profile (keyboard, mouse etc ..)
// tud_hid_report_complete_cb() is used to send the next report after previous one is complete
void hid_task(void)
{
  // Poll every 10ms
  const uint32_t interval_ms = 10;
  static uint32_t start_ms = 0;

  if (board_millis() - start_ms < interval_ms) {
    // not enough time passed
    return;
  }
  start_ms += interval_ms;

  // Remote wakeup
  if (tud_suspended() && pressed_keys > 0)
  {
    // Wake up host if we are in suspend mode
    // and REMOTE_WAKEUP feature is enabled by host
    tud_remote_wakeup();
  } else {
    // Send the 1st of report chain, the rest will be sent by tud_hid_report_complete_cb()
    send_hid_report(REPORT_ID_KEYBOARD);
  }

  hid_task_counter++;
  if (hid_task_counter%1000 == 0) {
    // quietly get voltages to update power state
    remote_get_voltages(1);
  }
  if (hid_task_counter%100 == 0) {
    refresh_menu_page();

    // power state debugging
    /*if (remote_get_power_state()) {
      gfx_poke_cstr(0,0,"[pwr on]");
    } else {
      gfx_poke_cstr(0,0,"[pwr off]");
    }
    gfx_flush();*/
  }
}

int led_brightness = 0;
int led_saturation = 255;
int led_hue = 127;

typedef struct RgbColor
{
  unsigned char r;
  unsigned char g;
  unsigned char b;
} RgbColor;

typedef struct HsvColor
{
  unsigned char h;
  unsigned char s;
  unsigned char v;
} HsvColor;

RgbColor HsvToRgb(HsvColor hsv)
{
  RgbColor rgb;
  unsigned char region, remainder, p, q, t;

  if (hsv.s == 0)
    {
      rgb.r = hsv.v;
      rgb.g = hsv.v;
      rgb.b = hsv.v;
      return rgb;
    }

  region = hsv.h / 43;
  remainder = (unsigned char)((hsv.h - (region * 43)) * 6);

  p = (unsigned char)((hsv.v * (255 - hsv.s)) >> 8);
  q = (unsigned char)((hsv.v * (255 - ((hsv.s * remainder) >> 8))) >> 8);
  t = (unsigned char)((hsv.v * (255 - ((hsv.s * (255 - remainder)) >> 8))) >> 8);

  switch (region)
    {
    case 0:
      rgb.r = hsv.v; rgb.g = t; rgb.b = p;
      break;
    case 1:
      rgb.r = q; rgb.g = hsv.v; rgb.b = p;
      break;
    case 2:
      rgb.r = p; rgb.g = hsv.v; rgb.b = t;
      break;
    case 3:
      rgb.r = p; rgb.g = q; rgb.b = hsv.v;
      break;
    case 4:
      rgb.r = t; rgb.g = p; rgb.b = hsv.v;
      break;
    default:
      rgb.r = hsv.v; rgb.g = p; rgb.b = q;
      break;
    }

  return rgb;
}

void led_set(uint32_t rgb) {
  led_task(rgb);
}

void led_set_hsv() {
  HsvColor hsv;
  RgbColor rgb;
  hsv.h = (unsigned char)led_hue;
  hsv.s = (unsigned char)led_saturation;
  hsv.v = (unsigned char)led_brightness;

  rgb = HsvToRgb(hsv);
  led_set((rgb.r<<16)|(rgb.g<<8)|(rgb.b));
}

void led_mod_brightness(int d) {
  led_brightness+=d;
  if (led_brightness>0xff) led_brightness = 0xff;
  if (led_brightness<0) led_brightness = 0;
  led_set_hsv();
}

void led_mod_hue(int d) {
  led_hue+=d;
  if (led_hue>0xff) led_hue = 0xff;
  if (led_hue<0) led_hue = 0;
  led_set_hsv();
}

void led_mod_saturation(int d) {
  led_saturation+=d;
  if (led_saturation>0xff) led_saturation = 0xff;
  if (led_saturation<0) led_saturation = 0;
  led_set_hsv();
}

void led_set_saturation(int s) {
  led_saturation = s;
}

void led_set_brightness(int b) {
  led_brightness = b;
  led_set_hsv();
}

void led_cycle_hue() {
  led_hue++;
  if (led_hue>0xff) led_hue = 0;
  led_set_hsv();
}

// Invoked when sent REPORT successfully to host
// Application can use this to send the next report
// Note: For composite reports, report[0] is report ID
void tud_hid_report_complete_cb(uint8_t instance, uint8_t const* report, uint16_t len)
{
  (void) instance;
  (void) len;

  uint8_t next_report_id = report[0] + 1;

  if (next_report_id < REPORT_ID_COUNT)
  {
    send_hid_report(next_report_id);
  }
}

// Invoked when received GET_REPORT control request
// Application must fill buffer report's content and return its length.
// Return zero will cause the stack to STALL request
uint16_t tud_hid_get_report_cb(uint8_t instance, uint8_t report_id, hid_report_type_t report_type, uint8_t* buffer, uint16_t reqlen)
{
  // TODO not Implemented
  (void) instance;
  (void) report_id;
  (void) report_type;
  (void) buffer;
  (void) reqlen;

  return 0;
}

#define CMD_TEXT_FRAME      "OLED"     // fill the screen with a single wall of text
#define CMD_OLED_CLEAR      "WCLR"     // clear the oled display
#define CMD_OLED_BITMAP     "WBIT"     // (u16 offset, u8 bytes...) write raw bytes into the oled framebuffer
#define CMD_POWER_OFF       "PWR0"     // turn off power rails
#define CMD_BACKLIGHT       "LITE"     // keyboard backlight level
#define CMD_RGB_BACKLIGHT   "LRGB"     // keyboard backlight rgb
#define CMD_RGB_BITMAP      "XRGB"     // push rgb backlight bitmap
#define CMD_LOGO            "LOGO"     // play logo animation
#define CMD_OLED_BRITE      "OBRT"     // OLED brightness level
#define CMD_OLED_BRITE2     "OBR2"     // OLED brightness level
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

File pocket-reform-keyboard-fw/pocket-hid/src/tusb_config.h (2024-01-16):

/*
 * The MIT License (MIT)
 *
 * Copyright (c) 2019 Ha Thach (tinyusb.org)
 *
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
 */

#ifndef _TUSB_CONFIG_H_
#define _TUSB_CONFIG_H_

#ifdef __cplusplus
 extern "C" {
#endif

//--------------------------------------------------------------------
// COMMON CONFIGURATION
//--------------------------------------------------------------------

// defined by board.mk
#ifndef CFG_TUSB_MCU
  #error CFG_TUSB_MCU must be defined
#endif

// RHPort number used for device can be defined by board.mk, default to port 0
#ifndef BOARD_DEVICE_RHPORT_NUM
  #define BOARD_DEVICE_RHPORT_NUM     0
#endif

// RHPort max operational speed can defined by board.mk
// Default to max (auto) speed for MCU with internal HighSpeed PHY
#ifndef BOARD_DEVICE_RHPORT_SPEED
  #define BOARD_DEVICE_RHPORT_SPEED   OPT_MODE_LOW_SPEED
#endif

// Device mode with rhport and speed defined by board.mk
#if   BOARD_DEVICE_RHPORT_NUM == 0
  #define CFG_TUSB_RHPORT0_MODE     (OPT_MODE_DEVICE | BOARD_DEVICE_RHPORT_SPEED)
#elif BOARD_DEVICE_RHPORT_NUM == 1
  #define CFG_TUSB_RHPORT1_MODE     (OPT_MODE_DEVICE | BOARD_DEVICE_RHPORT_SPEED)
#else
  #error "Incorrect RHPort configuration"
#endif

#ifndef CFG_TUSB_OS
#define CFG_TUSB_OS               OPT_OS_NONE
#endif

// CFG_TUSB_DEBUG is defined by compiler in DEBUG build
// #define CFG_TUSB_DEBUG           0

/* USB DMA on some MCUs can only access a specific SRAM region with restriction on alignment.
 * Tinyusb use follows macros to declare transferring memory so that they can be put
 * into those specific section.
 * e.g
 * - CFG_TUSB_MEM SECTION : __attribute__ (( section(".usb_ram") ))
 * - CFG_TUSB_MEM_ALIGN   : __attribute__ ((aligned(4)))
 */
#ifndef CFG_TUSB_MEM_SECTION
#define CFG_TUSB_MEM_SECTION
#endif

#ifndef CFG_TUSB_MEM_ALIGN
#define CFG_TUSB_MEM_ALIGN          __attribute__ ((aligned(4)))
#endif

//--------------------------------------------------------------------
// DEVICE CONFIGURATION
//--------------------------------------------------------------------

#ifndef CFG_TUD_ENDPOINT0_SIZE
#define CFG_TUD_ENDPOINT0_SIZE    64
#endif

//------------- CLASS -------------//
#define CFG_TUD_HID               1
#define CFG_TUD_CDC               0
#define CFG_TUD_MSC               0
#define CFG_TUD_MIDI              0
#define CFG_TUD_VENDOR            0

// HID buffer size Should be sufficient to hold ID (if any) + Data
#define CFG_TUD_HID_EP_BUFSIZE    64

#ifdef __cplusplus
 }
#endif

#endif /* _TUSB_CONFIG_H_ */

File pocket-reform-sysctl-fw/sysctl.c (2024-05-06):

/*
  SPDX-License-Identifier: GPL-3.0-or-later
  MNT Pocket Reform System Controller Firmware for RP2040
  Copyright 2023-2024 MNT Research GmbH
  
  fusb_read/write functions based on:
  https://git.clarahobbs.com/pd-buddy/pd-buddy-firmware/src/branch/master/lib/src/fusb302b.c
*/

#include <stdio.h>
#include <string.h>
#include "pico/stdlib.h"
#include "pico/binary_info.h"
#include "pico/sleep.h"
#include "hardware/i2c.h"
#include "hardware/spi.h"
#include "hardware/irq.h"
#include "hardware/rtc.h"
#include "fusb302b.h"
#include "pd.h"

#define FW_STRING1 "PREF1SYS"
#define FW_STRING2 "R1"
#define FW_STRING3 "20240416"
#define FW_REV FW_STRING1 FW_STRING2 FW_STRING3

#define PIN_SDA 0
#define PIN_SCL 1

#define PIN_DISP_RESET 2
#define PIN_FLIGHTMODE 3
#define PIN_KBD_UART_TX 4
#define PIN_KBD_UART_RX 5
#define PIN_WOWWAN 6
#define PIN_DISP_EN 7
#define PIN_SOM_MOSI 8
#define PIN_SOM_SS0 9
#define PIN_SOM_SCK 10
#define PIN_SOM_MISO 11
#define PIN_SOM_UART_TX 12
#define PIN_SOM_UART_RX 13
#define PIN_FUSB_INT 14
#define PIN_LED_B 15
#define PIN_LED_R 16
#define PIN_LED_G 17
#define PIN_MODEM_POWER 18
#define PIN_SOM_WAKE 19
#define PIN_MODEM_RESET 20
#define PIN_1V1_ENABLE 23
#define PIN_3V3_ENABLE 24
#define PIN_5V_ENABLE 25
#define PIN_PHONE_DPR 27
#define PIN_USB_SRC_ENABLE 28
#define PIN_PWREN_LATCH 29

// FUSB302B USB-PD controller
#define FUSB_ADDR 0x22
// MAX17320 protector/balancer
// https://datasheets.maximintegrated.com/en/ds/MAX17320.pdf
#define MAX_ADDR1 0x36
#define MAX_ADDR2 0x0b
// MP2650 charger
// https://www.monolithicpower.com/en/documentview/productdocument/index/version/2/document_type/Datasheet/lang/en/sku/MP2650GV/document_id/9664/
#define MPS_ADDR  0x5c

#define I2C_TIMEOUT (1000*500)

#define UART_ID uart1
#define BAUD_RATE 115200
#define DATA_BITS 8
#define STOP_BITS 1
#define PARITY    UART_PARITY_NONE

// battery information
// TODO: turn into a struct
// 4.8A x 3600 seconds/hour (per cell)
#define MAX_CAPACITY (4.0)*3600.0
float report_capacity_max_ampsecs =  MAX_CAPACITY;
float report_capacity_accu_ampsecs = MAX_CAPACITY;
float report_capacity_min_ampsecs = 0;
int report_capacity_percentage = 0;
float report_volts = 0;
float report_current = 0;
float report_cells_v[8] = {0,0,0,0,0,0,0,0};
bool reached_full_charge = true; // FIXME
bool som_is_powered = false;
bool print_pack_info = false;

void i2c_scan() {
  printf("\nI2C Scan\n");
  printf("   0  1  2  3  4  5  6  7  8  9  A  B  C  D  E  F\n");

  for (int addr = 0; addr < (1 << 7); ++addr) {
    if (addr % 16 == 0) {
      printf("%02x ", addr);
    }

    int ret;
    uint8_t rxdata;
    ret = i2c_read_blocking(i2c0, addr, &rxdata, 1, false);

    printf(ret < 0 ? "." : "@");
    printf(addr % 16 == 15 ? "\n" : "  ");
  }
}

uint8_t max_read_byte(uint8_t addr)
{
  uint8_t buf;
  i2c_write_blocking(i2c0, MAX_ADDR1, &addr, 1, true);
  i2c_read_blocking(i2c0, MAX_ADDR1, &buf, 1, false);
  return buf;
}

uint16_t max_read_word(uint8_t addr)
{
  uint8_t buf[2];
  i2c_write_blocking(i2c0, MAX_ADDR1, &addr, 1, true);
  i2c_read_blocking(i2c0, MAX_ADDR1, buf, 2, false);
  uint16_t result = ((uint16_t)buf[1]<<8) | (uint16_t)buf[0];
  return result;
}

uint16_t max_read_word_100(uint8_t addr)
{
  uint8_t buf[2];
  i2c_write_blocking(i2c0, MAX_ADDR2, &addr, 1, true);
  i2c_read_blocking(i2c0, MAX_ADDR2, buf, 2, false);
  uint16_t result = ((uint16_t)buf[1]<<8) | (uint16_t)buf[0];
  return result;
}

void max_read_buf(uint8_t addr, uint8_t size, uint8_t *buf)
{
  i2c_write_blocking(i2c0, MAX_ADDR1, &addr, 1, true);
  i2c_read_blocking(i2c0, MAX_ADDR1, buf, size, false);
}

void max_write_byte(uint8_t addr, uint8_t byte)
{
  uint8_t buf[2] = {addr, byte};
  i2c_write_blocking(i2c0, MAX_ADDR1, buf, 2, false);
}

void max_write_word(uint8_t addr, uint16_t word)
{
  uint8_t buf[3] = {addr, word&0xff, word>>8};
  int res = i2c_write_blocking(i2c0, MAX_ADDR1, buf, 3, false);
}

void max_write_word_100(uint8_t addr, uint16_t word)
{
  uint8_t buf[3] = {addr, word&0xff, word>>8};
  int res = i2c_write_blocking(i2c0, MAX_ADDR2, buf, 3, false);
}

void max_write_buf(uint8_t addr, uint8_t size, const uint8_t *buf)
{
  uint8_t txbuf[size + 1];
  txbuf[0] = addr;
  for (int i = 0; i < size; i++) {
    txbuf[i + 1] = buf[i];
  }
  i2c_write_blocking(i2c0, MAX_ADDR1, txbuf, size + 1, false);
}

float max_word_to_mv(uint16_t w)
{
  float result = ((float)w)*0.078125;
  return result;
}

float max_word_to_pack_mv(uint16_t w)
{
  float result = ((float)w)*0.3125;
  return result;
}

float max_word_to_ma(uint16_t w)
{
  float result = ((float)w)*0.3125;
  return result;
}

float max_word_to_time(uint16_t w)
{
  float result = ((float)w)*5.625;
  return result;
}

float max_word_to_cap(uint16_t w)
{
  float result = ((float)w)*1.0; // depends on Rsense, 1.0 @ 5mohms. otherwise 5.0μVh / Rsense
  return result;
}

float max_word_to_percentage(uint16_t w)
{
  // TODO: cap to 100%
  float result = ((float)w)*0.00390625;
  return result;
}

uint8_t mps_read_byte(uint8_t addr)
{
  uint8_t buf;
  i2c_write_blocking(i2c0, MPS_ADDR, &addr, 1, true);
  i2c_read_blocking(i2c0, MPS_ADDR, &buf, 1, false);
  return buf;
}

uint16_t mps_read_word(uint8_t addr)
{
  uint8_t buf[2];
  i2c_write_blocking(i2c0, MPS_ADDR, &addr, 1, true);
  i2c_read_blocking(i2c0, MPS_ADDR, buf, 2, false);
  uint16_t result = ((uint16_t)buf[1]<<8) | (uint16_t)buf[0];
  return result;
}

float mps_word_to_ntc(uint16_t w)
{
  float result = (float)(w&0xfff)*1.6/4096.0;
  return result;
}

float mps_word_to_3200(uint16_t w)
{
  float result = (w>>10)*100
    + ((w&(1<<9))>>9)*50
    + ((w&(1<<8))>>8)*25
    + ((w&(1<<7))>>7)*12.5
    + ((w&(1<<6))>>6)*6.25;
  return result;
}

float mps_word_to_6400(uint16_t w)
{
  float result = (w>>9)*100
    + ((w&(1<<8))>>8)*50
    + ((w&(1<<7))>>7)*25
    + ((w&(1<<6))>>6)*12.5;
  return result;
}

float mps_word_to_12800(uint16_t w)
{
  float result = (w>>8)*100
    + ((w&(1<<7))>>7)*50
    + ((w&(1<<6))>>6)*25;
  return result;
}

float mps_word_to_w(uint16_t w)
{
  float result = (w>>9)
    + ((w&(1<<8))>>8)*0.5
    + ((w&(1<<7))>>7)*0.25
    + ((w&(1<<6))>>6)*0.125;
  return result;
}

// tj=903-2.578*t
// tj-903=-2.578*t
// (tj-903)/-2.578=t

float mps_word_to_temp(uint16_t w)
{
  float result = (float)(w>>6);
  result = (result - 903) / -2.578;
  //result = 903-2.578*result;
  return result;
}

void mps_read_buf(uint8_t addr, uint8_t size, uint8_t *buf)
{
  i2c_write_blocking(i2c0, MPS_ADDR, &addr, 1, true);
  i2c_read_blocking(i2c0, MPS_ADDR, buf, size, false);
}

void mps_write_byte(uint8_t addr, uint8_t byte)
{
  uint8_t buf[2] = {addr, byte};
  i2c_write_blocking(i2c0, MPS_ADDR, buf, 2, false);
}

void mps_write_buf(uint8_t addr, uint8_t size, const uint8_t *buf)
{
  uint8_t txbuf[size + 1];
  txbuf[0] = addr;
  for (int i = 0; i < size; i++) {
    txbuf[i + 1] = buf[i];
  }
  i2c_write_blocking(i2c0, MPS_ADDR, txbuf, size + 1, false);
}
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

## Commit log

2021-04-30 initial keyboard pcb WIP
    [Cherry_-_ML1A-11NW.step, pocket-reform-keyboard-mcu.sch, pocket-reform-keyboard.kicad_pcb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]
2021-05-11 keyboard: first routed draft
    [S4B-PH-SM4-TB.stp, pocket-reform-keyboard-mcu.sch, pocket-reform-keyboard.kicad_pcb]
2021-05-17 keyboard: D-1, sent to fab
    [150080M153000.step, 2005280040.stp, pocket-reform-keyboard-mcu.sch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]
2021-07-28 add 13x8cm motherboard mockup
    [1747981-1.step, 467650301.stp, 480995701.stp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]
2021-11-19 WIP: component sketch of kailh ortho kbd 7 inch test
    [S4B-PH-SM4-TB.stp, pocket-reform-kbd-mcu.sch, pocket-reform-keyboard-kailh-ortho.kicad_pcb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]
2022-05-31 motherboard D-1 first schematic and placement
    [2199230-5.step, 3-2328724-1.step, 78800-0001.step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]
2022-06-08 motherboard: first routing
    [19-337-R6GHBHC-A01-2T.STEP, 9774010243R.stp, BK-879.STEP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]
2022-06-13 motherboard: routing snapshot
    [pocket-reform-motherboard.kicad_sch]
2022-06-14 snapshot before replacing usb7002
    [pocket-reform-motherboard.kicad_sch]
2022-06-14 routing snapshot with TUSB8040
    [pocket-reform-motherboard.kicad_sch]
2022-06-17 motherboard: resolve LCSC parts
    [3215-crystal.step, HTQFP-80.stp, SOD-128.step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]
2022-06-28 keyboard: tweak trackball mount, wire up tb buttons and leds
    [2005280040.stp, pocket-reform-kbd-mcu.kicad_sch, pocket-reform-kbd-mcu.sch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]
2022-06-28 motherboard: d-1 ordered version
    [pocket-reform-motherboard.kicad_sch]
2022-08-25 move old keyboard to attic
    [150080M153000.step, 2005280040.stp, Cherry_-_ML1A-11NW.step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]
2022-08-25 keyboard: add D-1 version (beware, has hw bugs)
    [pocket-reform-kbd-mcu.kicad_sch, pocket-reform-keyboard-kailh-ortho.kicad_sch]
2022-08-25 motherboard: add some notes
    [pocket-reform-motherboard.kicad_sch]
2022-08-26 HID: fix more c typing problems
    [main.c, oled.c, oled.h]
2022-08-26 HID: fix display width
    [oled.c, oled.h]
2022-12-15 keyboard d-2 done and exported for assembly
    [pocket-reform-kbd-mcu.kicad_sch, pocket-reform-keyboard-kailh-ortho.kicad_sch]
2022-12-26 kbd: oled fixes and backlight WIP
    [main.c, oled.c, oled.h]
2023-01-12 pocket HID: let PIOs handle the LED backlight; introduce hue/value setting via trackball;
2023-03-20 pocket-hid: fix compiler warnings; lower oled brightness
    [main.c, oled.c, oled.h]
2023-04-12 charger snapshot
    [21-0139I_T2444-4_MXM.step, S2B-PH-SM4-TB.stp, S9B-PH-SM4-TB.stp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]
2023-04-12 add WIP panel and bezel PCBs
    [pref-display-back-d5-gold.kicad_pcb, pref-display-back-d5.kicad_pcb, pref-display-front.kicad_pcb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]
2023-04-12 add missing keyboard back PCB
    [pref-keyboard-back-d1-fr4.kicad_pcb]
2023-08-07 d-2 pcbs TODO
    [pocket-reform-kbd-mcu.kicad_sch, pocket-reform-motherboard.kicad_sch]
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2023-08-14 sysctl: increase charge current, put 100ms sleep in timeout state
2023-08-24 WIP: work on mb schematic
    [pocket-reform-motherboard.kicad_sch]
2023-08-24 WIP: motherboard: move things around
    [pocket-reform-motherboard.kicad_sch]
2023-08-25 WIP: mb: more shuffling
    [105450-0101.step, SM04B-SRSS-TB(LF)(SN)--3DModel-STEP-56544.STEP, TSM-103-01-L-DH.step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]
2023-09-28 motherboard schematics basically done
    [pocket-reform-motherboard.kicad_sch]
2023-09-29 D-2 fully routed
    [SM05B-SRSS-TB(LF)(SN)--3DModel-STEP-418109.STEP, pocket-reform-motherboard.kicad_sch]
2023-10-03 motherboard: D-3 production snapshot
    [pocket-reform-motherboard.kicad_sch]
2023-10-03 keyboard D-3: production snapshot
    [SM04B-SRSS-TB(LF)(SN)--3DModel-STEP-56544.STEP, pocket-reform-kbd-mcu.kicad_sch, pocket-reform-keyboard-kailh-ortho.kicad_sch]
2023-11-08 keyboard-fw: update for latest tinyusb; enable usb Errata RP2040-E5
    [main.c]
2023-11-20 mb: snapshot before TUSB8041 change
    [pocket-reform-motherboard.kicad_sch]
2023-11-22 WIP mb audio rerouting
    [pocket-reform-motherboard.kicad_sch]
2023-11-24 motherboard: R-1
    [JXD-G2406S.obj, MP23ABS1TR.obj, SM02B-SRSS-TB-LF--SN---3DModel-STEP-56544.STEP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]
2023-12-06 snapshot before change to MP2650
    [pocket-reform-charger.kicad_pcb, pocket-reform-charger.kicad_sch]
2023-12-12 sysctl: updates for motherboard r-1 - add usb power sourcing enable - add latch chip support for power/display enables - update modem pins - lower system freq to 48mhz
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2023-12-27 add latest case files
    [PREF-bottom_enclosure_2023.09.06.step, PREF-top_enclosure_2023.11.21.step]
2023-12-27 add case plate parts
    [pref-display-back-d7-gold.kicad_pcb, pref-display-front-d7.kicad_pcb, pref-keyboard-bezel-d6.kicad_pcb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]
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2023-12-27 add trackball cup model
    [pocket-reform-trackball-cup-plate31.stl, pocket-reform-trackball-cup.scad]
2023-12-27 update charger pcb
    [pocket-reform-charger.kicad_pcb, pocket-reform-charger.kicad_sch, pocket-reform-charger.xlsx]
2023-12-27 update motherboard pcb
    [pocket-reform-motherboard-r2-bom.xlsx, pocket-reform-motherboard.kicad_sch]
2023-12-27 add headphone/switch pcb
    [73412-0110.stp, CUI_SJ-43516-SMT-TR.step, SM05B-SRSS-TB(LF)(SN)--3DModel-STEP-418109.STEP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]
2023-12-27 update keyboard pcb
    [KMR221GLFS.step, pocket-reform-kbd-mcu.kicad_sch]
2024-01-16 kbd: change power key to hyper+return, test wake with f12
2024-01-19 add tweaked battery holder models
    [pref-assembly-20240112-BattHolder1-reexport.stl, pref-battholder-countersink-prod-a.stl, pref-battholder-countersink-prod-b.stl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]
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2024-04-12 sysctl: implement more spi and serial reporting functionality
2024-04-12 pocket-hid: port OLED menu from reform incl battery status, some refactoring
2024-04-17 various kicad bumps
    [pocket-reform-charger.kicad_pcb, pocket-reform-charger.kicad_sch, pocket-reform-charger.xlsx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]
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2024-05-06 sysctl: fix logic error/hang around spi poweroff
    [sysctl.c]
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2024-05-31 keyboard-fw: make it so that the trackball buttons do what's said in the manual
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

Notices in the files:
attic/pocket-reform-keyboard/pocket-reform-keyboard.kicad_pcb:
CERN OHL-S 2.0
